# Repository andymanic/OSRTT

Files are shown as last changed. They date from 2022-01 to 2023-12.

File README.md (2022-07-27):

# OSRTT
Open Source Response Time Tool - LCD response time tool, includes hardware, firmware and software!

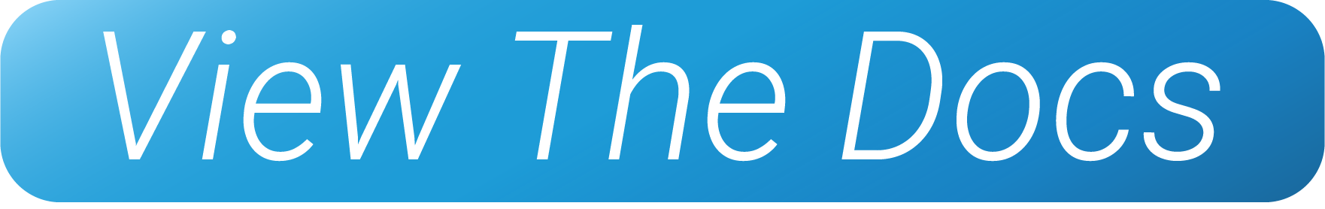
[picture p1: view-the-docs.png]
View the docs

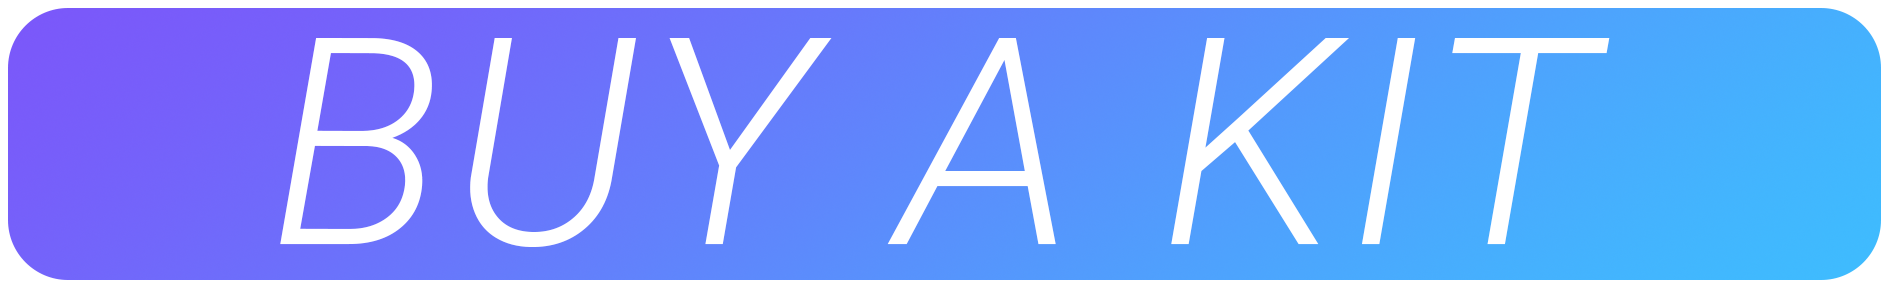
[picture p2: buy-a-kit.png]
Buy a kit


# Project Aim
The goal of this project is to offer an open source, cost effective solution to testing LCD monitor's input lag. The hardware as described in the circuit diagrams is required, as is a copy of the Windows Forms app. The hardware isn't too difficult to build if you'd like to do it yourself, and the software is fully open source so you are welcome to make alterations to suit your testing needs.

The C# based program handles all interaction with the hardware, primarily over Serial (over USB), both connecting to the board, updating the board's firmware (using the [Arduino CLI](https://github.com/arduino/arduino-cli), and recording results. It's also capable of setting how many repeats of the test it will do before averaging them out (max supported 10 repeats). 

My aim was to keep everything as transparent as possible, so when a test is begun it will create a numbered folder within the /Results folder using the monitor, refresh rate and connection you are using. It will save the raw results and processed results to individual files for each run, then will output a "FINAL-DATA-OSRTT.csv" file that averages all the processed data. You can now use the Results View form to both view the data as heatmaps, and the raw data in graph form.

# Installation
- Download the latest zip file from the [releases](https://github.com/andymanic/OSRTT/releases) page. 
- Extract the OSRTT folder anywhere you like, personally I keep it on the desktop.
- Run the "OSRTT Launcher.exe" program. On first run it will ask to install additional files, openning a CMD window to run arduino CLI commands.

# Usage
- Assuming you have the hardware built, connect it via USB then run the launcher. **CONNECT IT DIRECTLY TO YOUR SYSTEM, OR AT LEAST A POWERED HUB**
- On the first launch on a new device, you will be prompted to allow installation of additional files. This is installing the Arduino & Adafruit SAMD cores and Adafruit board library in %APP_DATA%\Arduino15. It may take a minute or two, but is necessary to connect to the board.
- Once the launcher has connected to the device, you can set how many times the test should run, what framerate limit to use, if VSync should be enabled and for how long the device should capture each transition.
- You can then launch the test program with the large button at the top of the section.
- Once the test program is up, press the button on the device. Use numbers 1 - 8 to limit the frame rate: 1 = 1000, 2 = 360, 3 = 240, 4 = 165, 5 = 144, 6 = 120, 7 = 100, 8 = 60
- Assuming the monitor's brightness is in the correct range, the device will run through the test sequence. By default it will run 3 times, although you can set that in the launcher. 

# Building from source
If you'd prefer to compile it yourself, you'll need to download the latest [Arduino CLI](https://github.com/arduino/arduino-cli), and place it in a folder called "arduinoCLI" in the working directory of the launcher. 

# Current hardware limitations
- ~160 nits of brightness is the recommended target using the included 3D printed casing. Different Z heights for the sensor to the display lead to differing maximum supported brightness levels and vary the noise level
- The current design doesn't effectively filter all monitor backlight strobing frequencies. This doesn't affect the final results too heavily but is worth noting here.
- 10 repeats of the test are the maximum the current version of the firmware - this isn't a fixed limit and could be changed in future

# Current software limitations
- The processing algorithm doesn't currently measure cumulative deviation. Luckily I don't think it'd be all that hard to add, and since all the raw data gets saved already you can always re-import any existing folders to re-process that data with any changes to the alogrithm!
- The serial connection isn't perfect - I'm sure this could be made better so if you've done reliable data transfer over serial with C# please do have a look! My biggest issue is with the amount of data, it's likely upwards of 50KB per line so the in buffer size is now 64KB just in case.

# Current human limitations
Please be patient when it comes to solving issues or implementing new feature requests. I'm only human, a bearly functional one at that. I struggle with mental and physical limitations and disabilities, and run both [TechteamGB](https://youtube.com/techteamgb) and [At The Wheel](https://youtube.com/c/atthewheel), and run the short linking platform [Locally Links](https://locallylinks.com), so please excuse any delays. 

# Support the project
If you would like to support this project, there are a number of both direct and indirect ways to help. As stated above, the main goal of this project is to create an accessible solution for testing monitor response times. I want as many reviewers and enthusiasts to have the ability to test this with a degree of accuracy that is currently painstaking to reach. 
- Non-monetary support: please do reach out to your favourite reviewers who don't currently test monitor response times and (politely!) ask them to check out the project. 
- Buy one prebuilt by me: I very much appreciate many won't have the equipment, skills or time to build these units themselves, which is why I'm happy to purchase the parts in bulk, solder everything up, flash the bootloader and firmware, and 3D print the case. I'm still finalising that process, so haven't got a final price as of yet but I'm expecting it to be around $100/£75. Ping me [an email](mailto:inbox@techteamgb.com) if you want one!
- Buy me a ~~Beer~~ - ~~Coffee~~ - Cookie. I like cookies. [Paypal](https://paypal.me/techteamgb) | [Patreon](https://patreon.com/techteamgb)

# Warranties & Guarantees
I should make it clear that this software, circuit diagrams, STL and Gerber files, and any hardware bundles I produce, are provided AS-IS. I can't guarantee I've accounted for every possibility or edge case, or even that what I've written will be infinitely reliable. I have it output every step of processing, so if you want to verify any result you can do so manually. 

# Licensing 
I've gone with the GNU GPL V3 License for the whole project, both hardware and software. That means you are free to use anything here as you like, on the condition that anything you make with this is also open source. If you'd like to use anything here in a closed-source project or if you'd like to manufacture the hardware elements commercially, please send me [an email](mailto:inbox@techteamgb.com).

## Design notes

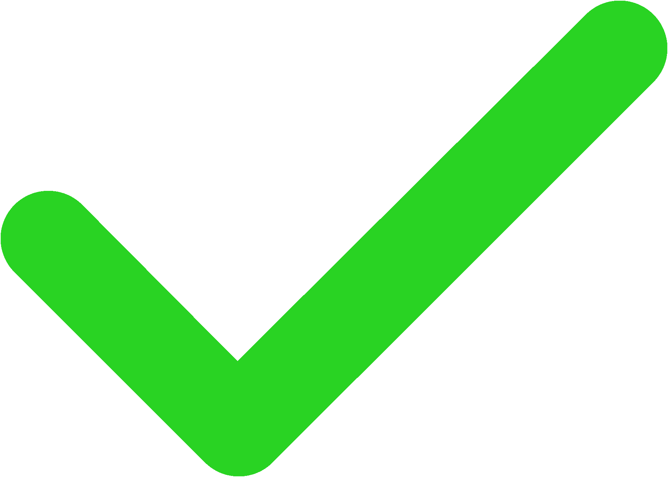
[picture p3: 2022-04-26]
OSRTT Launcher/OSRTT Launcher/Resources/check.png

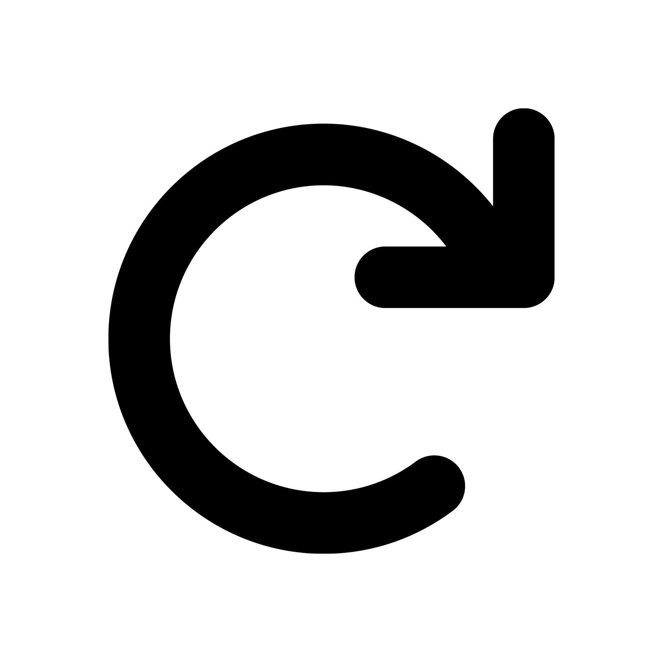
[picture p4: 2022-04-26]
OSRTT Launcher/OSRTT Launcher/Resources/arrow-rotate-right.png

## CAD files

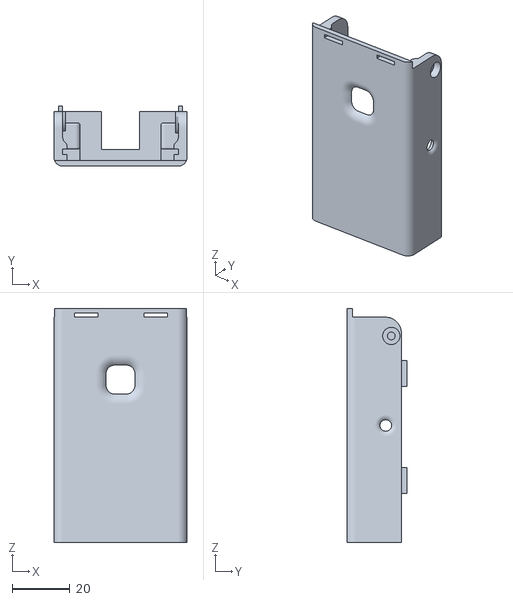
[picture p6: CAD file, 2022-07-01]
Hardware/V4Base.stl
46.0 x 20.9 x 81.0

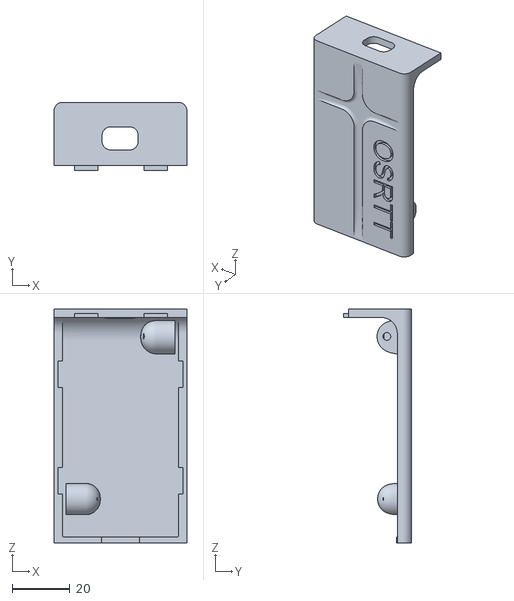
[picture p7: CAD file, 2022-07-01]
Hardware/V4Lid.stl
46.0 x 23.7 x 81.0

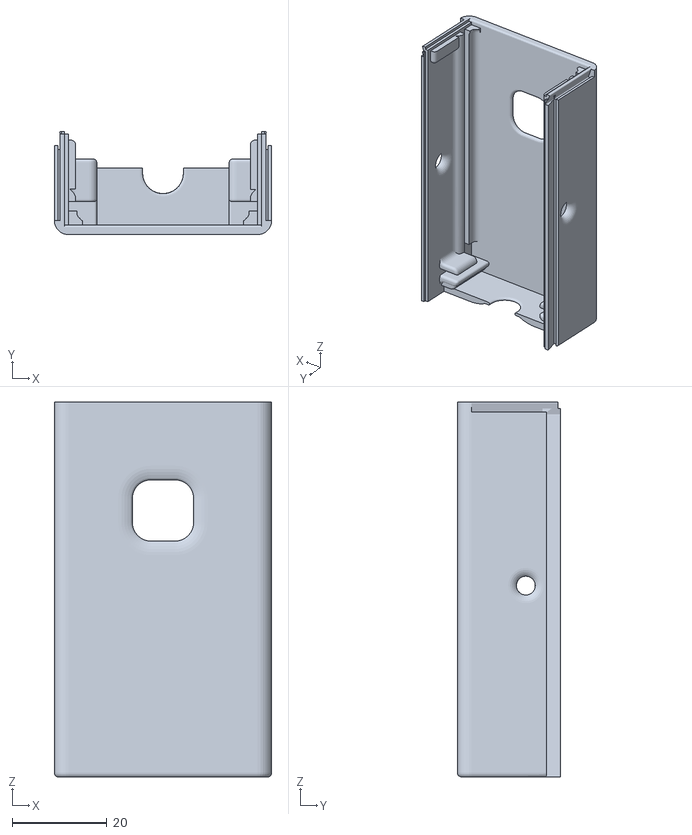
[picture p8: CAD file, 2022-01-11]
Hardware/V3Base.stl
46.0 x 21.9 x 79.4

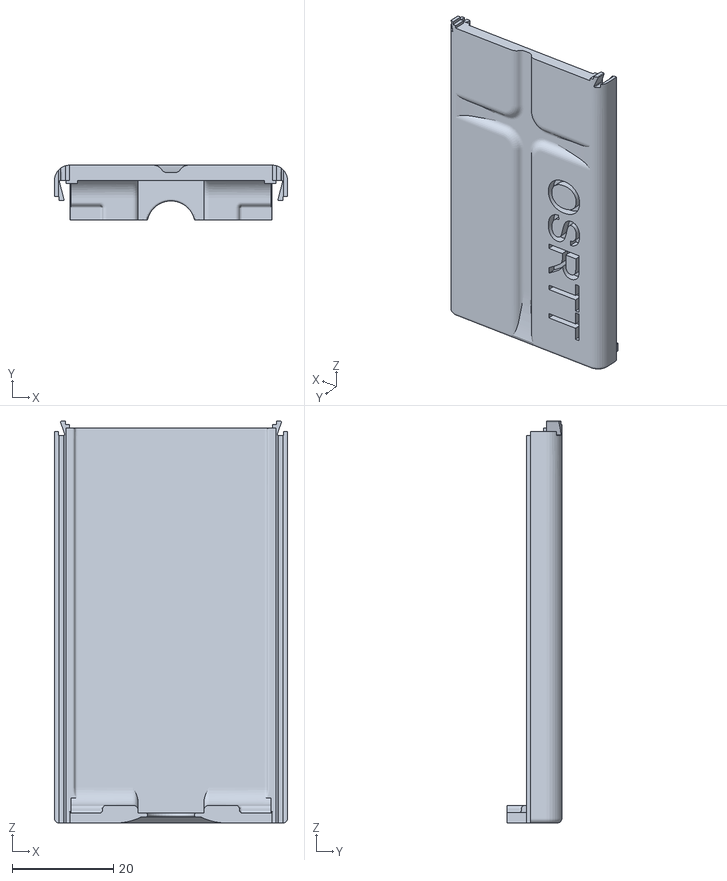
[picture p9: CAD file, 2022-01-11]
Hardware/V3Top.stl
46.0 x 10.8 x 79.4

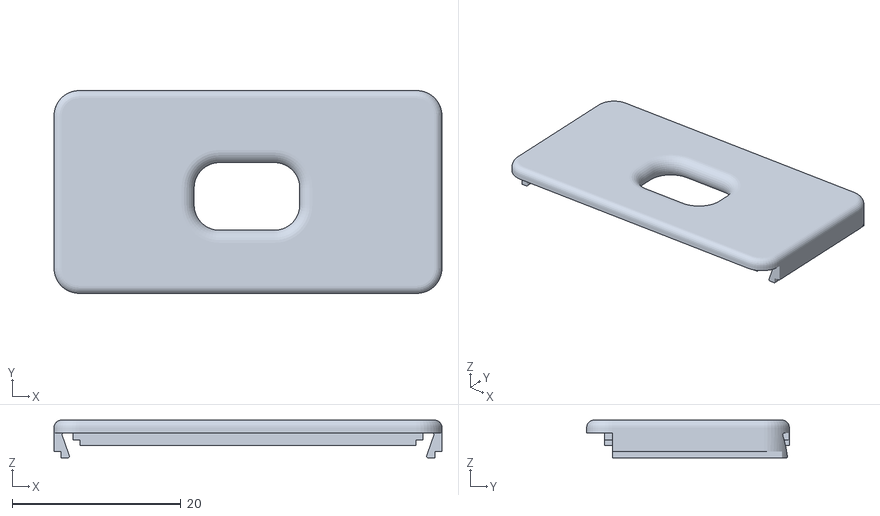
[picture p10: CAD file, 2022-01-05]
Hardware/V3Back.stl
46.0 x 24.0 x 4.50

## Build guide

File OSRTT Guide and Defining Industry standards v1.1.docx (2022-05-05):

OSRTT Guide – Understanding the Many Options, Deciding on Recommended Settings, and Ensuring Consistency Across Reviewers
Issue 1.1, last update 4 May 2022

Introduction

The OSRTT provides a wide range of options and features designed to test all elements of a display’s performance for pixel transitions and response times. There are many ways to analayze the data, and many possible ways you may wish to present the data to your readers and viewers depending on what you are trying to capture and cover. To ensure there is consistency across the industry as much as possible, and clear guidance for an average consumer trying to make sense of the data, it’s important that we try to retain some level of uniformity if we can in the way this data is presented.

This guide is to explain what the different options and measurements methods can do, how they might be interpreted and how ideally they should be presented to readers/viewers to achieve that consistent approach. It covers the “g2g” response time measurements as well as “overshoot” calculations.

The guide has been produced in conjunction with several established reviewers who already carry out this kind of testing, including TFTCentral and Hardware Unboxed. The aim is for it to represent an “industry standard” for this kind of display measurement if possible.

TL;DR: Summary of Recommendations

- Make sure you have consistency in your PC and display setup for this testing wherever possible (explained below)
- When presenting G2G measurements please try and use the suggested names in this guide – please do not bundle everything under the name “response time” without explanation of what you are presenting as there are many different approaches possible
- Please state which method you are using if possible including any tolerance levels etc as it helps ensure results can be compared between reviewers
- The OSRTT ‘recommended settings’ option can be left selected if you wish although it is probably useful to understand what it is capturing and what will be output in the results as explained below. This mode uses:
  - Gamma corrected response times
  - The “complete response time” (this is always captured in the data, no matter what options you select)
  - “Initial response time” (the bit before any overshoot – explained later) with a fixed RGB 5 offset tolerance level
  - “Visual response time” (including any overshoot in the figure – explained later) with a fixed RGB 5 offset tolerance level
  - Gamma corrected overshoot in RGB values
- If you instead want to instead use other settings away from the ‘recommended settings’ mode you can select “advanced settings” in the menu, but please take note of the guide below when selecting options, and when presenting data to your audience.

PC and Display Setup

1. Make sure the display you are measuring has been warmed up for a suitable amount of time, at least 30 minutes. Ideally you would run some dynamic content like a game, video or perhaps leave the full screen version of this TestUFO.com (https://www.testufo.com/photo) test running if you want. The OSRTT software will warn you if it detects you might not have warmed up for long enough
2. Make sure that you have monitor features like blur reduction mode (which would strobe the backlight) or any local dimming disabled. These would cause variations in the light measurement and lead to errors in calculations.
3. Set your graphics card to the refresh rate you want to measure:
  a. For PC gaming usage it is best to set it to the maximum the screen will support. The software will allow you to measure the impact of VRR (Variable Refresh Rates – G-sync and FreeSync) where the frame rate drops below this, by limited the FPS settings, so you do not need to change the refresh rate setting for that.
  b. You may also want to test the screen at a fixed refresh rate for certain situations. For instance, you may want to set the graphics card refresh rate to a fixed 60Hz input, and disable G-sync / FreeSync to simulate the performance if you had a Blu-ray player or 60Hz games console connected. Likewise you could also set the refresh rate at 120Hz to capture the performance for a 120Hz input from modern consoles like the PS5 or Xbox Series X.
4. Position the device so it is measuring the centre of the screen as best you can – the actual sensor is located behind the purple light you can see on the front of the unit, so use that as a guide.
5. If the screen supports VRR (G-sync or FreeSync) then for PC gaming it is probably best to test with this enabled. Some screens show different performance with VRR turned on and off, so it’s probably best to measure with this on since most people will use this feature.

Notes, warnings and comments:

1. Displays that still feature PWM for backlight dimming (thankfully very rare nowadays) may create issues with the measurements since the brightness will fluctuate and this may mess up the calculations. It should be possible to still calculate response times but you may need to more closely validate or calculate the results using the ‘Graph View Template’ sheet. The software uses a moving average filter to reduce noise before processing the data. It’s adaptive based on how noisy the data is, although in some very niche cases it may fail to process, hence the need to check and validate your results.
2. On some displays where the transitions reach towards black, and the contrast ratio of the display is low, you may find the results hard to capture. You may need to exclude these from your results table if the figures look odd. You can also check the data in the ‘Graph View Template’ sheet if you want
3. Why not capture more transitions in the table? – after lots of experimentation and discussion we felt that more data was not necessarily better here. It over-complicated things for readers, added unnecessary time to testing, and created issues with measurements when transitions were very close together. We felt that the provided 30 transitions was the most appropriate sample set to use
4. Please remember these measurements and numbers can never fully replace the need for subjective assessment in games, movies and other fast motion content.

What do we mean by display pixel “response time”? – it might not be as simple as you think

First of all, we should consider what the term “response time” really means in the display market. It is not as simple as just saying “it’s the time it takes for a pixel to change from one colour to another”. That’s not actually what the term “response time” means strictly.

For over 20 years the definition of response time in the display market is actually, in simple terms: “the time taken to switch between two colours, allowing for a small leeway of 10% either side”. Put another way, “It’s the time to go from close to the starting colour, to close to the end colour”.

Actually we are measuring changes in grey shade of the pixels based on how much light they let through from the backlight (for LCD displays at least), from RGB 0 (black) to 255 (white). The colour filters are applied on top so from now on we will talk about this as changes in grey shade, which is where the term “grey to grey” (G2G / GtG) comes from in the market.

Represented on a graph measuring the change, it would look something like this:

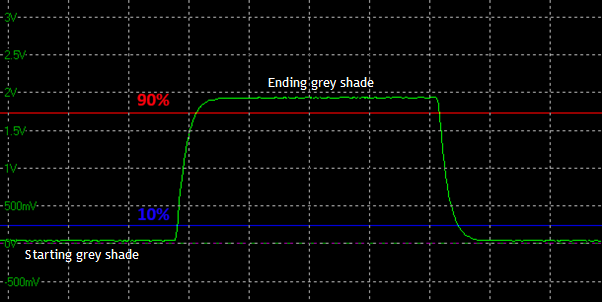
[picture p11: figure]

Where the bottom green line of the graph is the darker grey shade it is changing FROM, and the top green line represents the lighter grey shade it is changing TO. The light from the display is picked up by a photosensor or similar device and converted to a voltage on the graph.

The time it takes to switch from the bottom green line (dark shade) to the top green line (light shade) would be the full transition time of the change, but actually the definition of the “response time”, as defined a long time ago and uniformly adopted by panel and display manufacturers, is the time it takes to change within a 10% tolerance of either shade. That’s represented by the 10% blue line close to the starting grey shade, and to the 90% red line which is close to the end grey shade. That’s what the term “response time” officially means in the display industry.

The reasons for this being adopted were:

1) Because having a modest 10% tolerance level is widely adopted in various areas of electronics and measurement, so it seems to make sense to do the same here
2) It helps to some degree reflect a more realistic view of the time it takes to get “close enough” to the desired colour from a visual point of view. For instance, if you’re transitioning to black, there is a point where very dark grey is “close enough” to look visually indistinguishable and very similar. A small tolerance accounts for this leeway in what you see visually. This is a good thing for displays as after all, it’s all about what you see as a user.
3) It also helps avoid some complications with measurement methods, removing any noise or variation as you get close to certain shades, especially towards black.

Let’s call this the “traditional response time” for reference.

If you want to, you can measure using this method from OSRTT by

- Select the test settings menu > switch to advanced mode at the top > in response time settings section select tolerance style as “light level” > select “10% light level” option as shown below.

We do not believe that this is the best way to present this measurement data any more, and would advise using the other methods discussed below. It is included for completeness and reference.

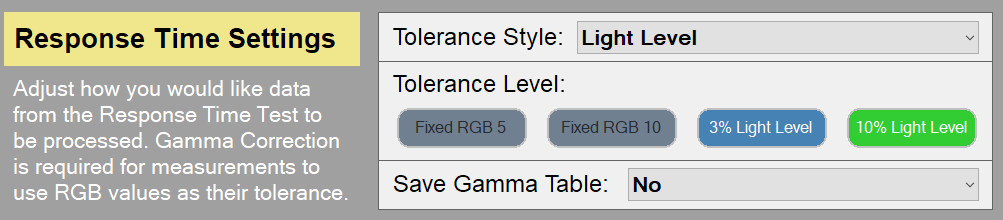
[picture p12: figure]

Gamma Correction provides a more accurate view of visual experience

So that’s the definition of what “response time” actually means officially. In 2020 a video by a5hun at Aperturegrille on YouTube (https://www.youtube.com/watch?v=MbZUgKpzTA0), and then later discussed at length by Hardware Unboxed (https://www.youtube.com/watch?v=-Zmxl-Btpgk) and TFTCentral (https://tftcentral.co.uk/articles/response_time_testing) highlighted a flaw with the traditional measurement method. This old method did not account for the impact of display gamma, and so the way the tolerance levels of 10% and 90% were used led to some issues.

You can refer back to the resource linked above for a lot more information, but a better method was suggested that would “gamma correct” the measurements and therefore provide a more realistic reflection of the performance from a visual point of view. The tolerance levels of 10 and 90% can still be kept if desired, but now the measurements are based on the actual visual RGB values instead of just the voltage that is converted from the light output. This removes the error with just referring to voltage scales on the data that were being used before in the “traditional response time method”.

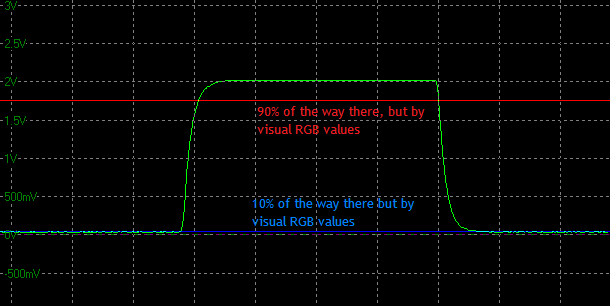
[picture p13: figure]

This is useful to provide a more complete view of what you would see in real use and we would recommend leaving “gamma corrected response times” enabled in the software, unless you have some specific reason to measure using the old traditional method.

- Select the test settings menu > switch to advanced mode at the top > in response time settings section select tolerance style as “RGB values (Gamma corrected)l” > select “10% light level” option as shown below.

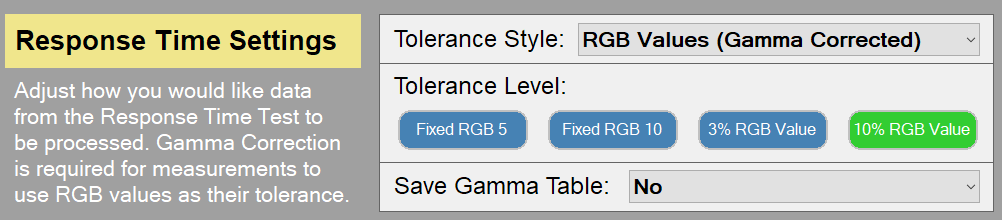
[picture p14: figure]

From there the question becomes – what is a reasonable tolerance / offset level to use, if any, and which part of the response curve do you want to capture?

-----------------------------------------------------------------------------------
Option 1 – Measure the Complete Response Curve (0 – 100%)
Known as the “Complete Response Time”

One option for the OSRTT tool is to consider the FULL transition time, the time it takes to fully change from one shade to another. This would be represented on the response curve graph as follows, measuring between the blue and the red lines without any tolerance baked in. It is the total time taken to fully change from the starting grey shade, to the target grey shade.

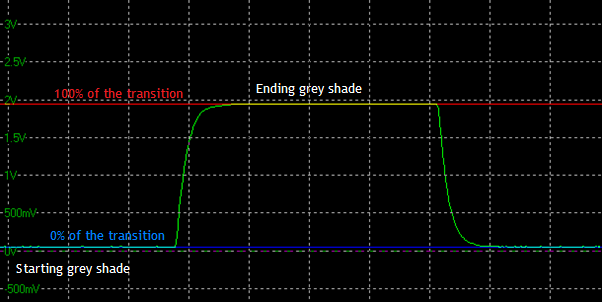
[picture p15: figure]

This may be favoured by some people as a measure of the full transition time – but we cannot call this the “response time” really as that’s not what we are measuring any more.

The recommendation is that if this data is to be used and presented, this should really be labelled as the COMPLETE RESPONSE TIME

Some people may prefer this approach as a very strict measure of the total time it takes to switch from one shade fully to another. However, there are some limitations with this approach:

1) There is no consideration for when a transition has reached “close enough” to the target colour and so is visually indistinguishable. Is it fair to measure the curve to where it has to reach the final end shade if it got visually to the same thing much sooner? You will see how the response curves taper off when it gets close to the end points of the transition. The real question is how close does it need to get to visually represent the completion of the transition?
2) Some screens show a particularly long taper at the end of a transition as it finishes that last little bit. In some extreme cases if you were then measuring this “total transition time” it would extend the response time to maybe 20ms+. Is it fair to do that when it ctually reached 90% or even 95% of the way there, and looked visually the same?
3) Note: Where overshoot is present (discussed later) the “complete transition time” will incorporate this as well, as it measures the time it takes to get to the final RGB state AFTER the overshoot has happened. This will also add significant time to the G2G measurement. This is discussed more later, but it’s important to keep in mind for these measurements.

There is perhaps merit and interest in capturing this “complete response time” for some users, but we also need to also keep in mind what we are ultimately trying to achieve here – and that is to provide a measurement that is representative of how the display appears visually to the user. As a result we do not recommend using the ‘total response time’ as it is overly strict and prone to causing unfair measurements.

Note that if you do want to use this data, is is captured by default in the OSRTT output data CSV files as “complete response time”, you do not need to select that in the software, it will always be included

-----------------------------------------------------------------------------------------------------------
Option 2 – Using a tight tolerance level to capture nearly all the initial response time curve (3 – 97%) but excluding overshoot

At the time of writing in Mar 2022 this is the method currently used by Hardware Unboxed and discussed in their video here (https://www.youtube.com/watch?v=-Zmxl-Btpgk&feature=youtu.be). The desire is to capture as much of the response curve as possible, but eliminating some of the problems discussed above with getting very close to the desired shade, removing the issue with the slow tapering off, and also ignoring the overshoot impact in the response time figure itself. Overshoot is captured as a separate table of data, it is not just ignored.

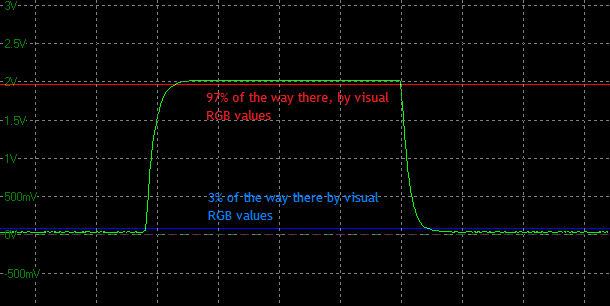
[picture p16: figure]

This can be selected within OSRTT using the following option:

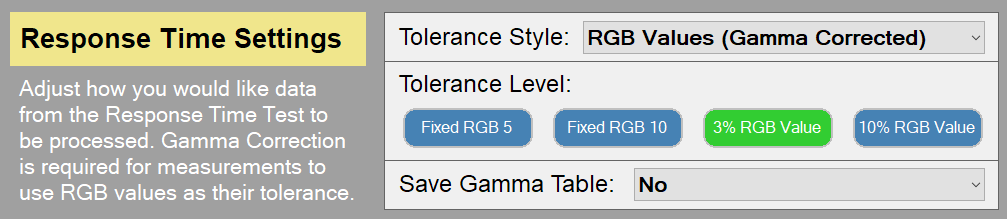
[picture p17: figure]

This avoids some of the issues in presenting the “complete response time” but also has some limitations of its own:

1) The % will result in the actual RGB tolerance being variable each time. For instance when measuring from 0 > 100 RGB as a transition, this would mean you’re really measuring between RGB 3 and RGB 97 values. But if you measure from 0 > 200 RGB you are measuring between RGB 6 and RGB 194 because the total range is wider. So on the one hand, it is being more strict and only allowing an RGB tolerance of 3, and in the other it’s measuring a slightly more relaxed tolerance of 6.  This doesn’t make a huge difference to the resulting measurements as really it’s trying to capture nearly the whole “total transition time” anyway, but it does cause some variance.
2) Like with the “total transition time” approach, it doesn’t necessarily consider the visual difference as well and whether a shade gets “close enough” sooner than the strict tolerance levels used, especially when measuring transitions close together. It may also in some cases capture portions of the slow tapering off in the grey shade, where it may be visually indistinguishable in practice.

We do not recommend using a % tolerance level for the above reasons

----------------------------------------------------------------------------------------------------------
Option 3 – Using the original tolerance levels but now with gamma correction
(10 - 90%)

There is of course the option to stick with the original 10 – 90% tolerance levels that have been used in the market for 20+ years. It is worth including the gamma correction to more accurately capture the response times relative to what you see in RGB values. This removes some of the errors in sticking only to the voltage reading on the graphs, and allows you to account for display gamma.

The options should be selected as follows in the OSRTT software:

The limitations with this approach are:

1) Like with the 3 – 97% tolerance levels discussed above, using any % will result in the actual RGB tolerance being variable each time. In this instance when measuring from 0 > 100 RGB, this would mean you’re really measuring between RGB 10 and RGB 90. But if you measure from 0 > 200 RGB you are measuring between RGB 20 and RGB 180 because the total range is wider. So on the one hand, it is being more strict and only allowing an RGB tolerance of 10, and in the other it’s measuring a more relaxed tolerance of 20.  Visually you are not being consistent in the tolerance allowed to get “close enough” to the end shade. This is far more variable when using 10/90% tolerance levels. If you are going to the lengths of correcting for gamma in the response times in order to provide a better indication of visual experience, this variation may not be ideal.

We do not recommend using a % tolerance level for the above reason

-------------------------------------------------------------------------------------------------------
Option 4 – Fixing an RGB tolerance level with gamma correction (+/- RGB 10)

This the approach favoured by TFTCentral in their measurements. Gamma correction is used to provide a more realistic measurement of what you see visually, accounting for display gamma and avoiding the pitfalls and errors from the old “traditional response time” method.

To overcome the issues with using a % discussed in the above options 2 and 3, and having variable RGB tolerance depending on the size of the range as a result, a fixed RGB tolerance level is selected. Based on lengthily visual experimentation and testing, an RGB balance of +/- 10 was deemed appropriate to get “close enough” to the desired grey shade from a visual point of view without being overly strict or too relaxed.

The TFTCentral article (https://tftcentral.co.uk/articles/response_time_testing) explains the approach and how they reached this method in more detail. This can be selected in OSRTT using the following option:

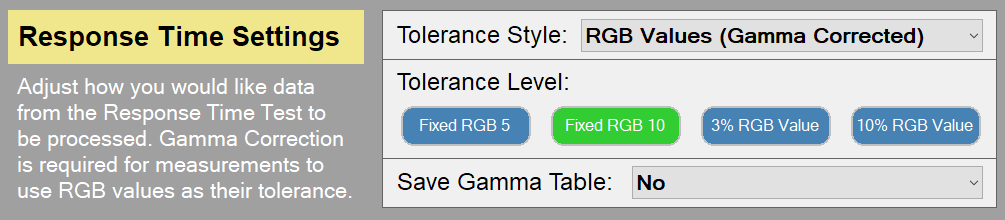
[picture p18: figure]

One possible concern with this approach is that for transitions that are close together (e.g. 0 – 51), there would not be much of the transition curve to measure, as you would be measuring from RGB 10 to RGB 41 in theory. This could still be considered “fair” visually since the two shades you are switching between are already very close together. Obviously if you were measuring something even closer like 0 > 20 RGB, you’d be measuring a range of 0!

You could also instead use…

Option 5 – Fixing a tighter RGB tolerance level with gamma correction (+/- RGB 5)

Instead of using a tolerance of RGB 10, you could use a tighter RGB 5 tolerance. This captures more of the response time curve. This is the default option in the “recommended settings” although you may consider this overly strict from a visual point of view, you would have to decide whether you feel it is a better option than using RGB 10 as being “close enough” to the target grey shade..

If you want to use a fixed RGB 5 tolerance you can select it in the software using the following options:

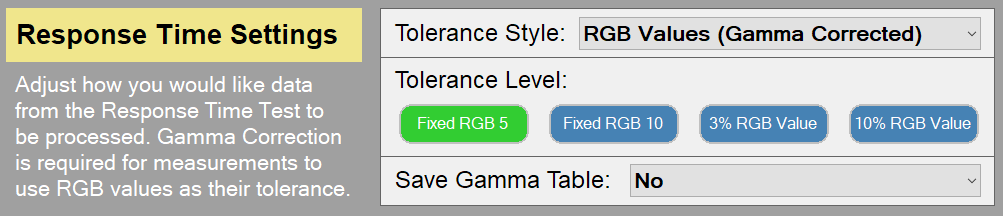
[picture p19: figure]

We recommend using a fixed RGB tolerance level when measuring G2G response times, you can use either RGB 10 or RGB 5 depending on your preference. TFTCentral have settled with RGB 10 as explained in their article here (https://tftcentral.co.uk/articles/response_time_testing).

Overshoot Calculations

Above covers the pixel transition times and “G2G” figures. The other aspect that can be measured by OSRTT is “overshoot”. On a response time measurement graph the overshoot would be represented by the peak where the shade reaches beyond the desired grey shade, before it then drops back down to where it was supposed to be. This can also appear on the downward “fall time” as well at the end of the curve which would be “undershoot”.

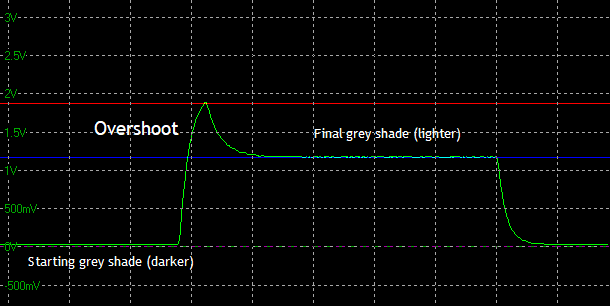
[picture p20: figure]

There are a few options included within the software for this:

1) Gamma corrected (RGB values) overshoot – RECOMMENDED - this will measure how many RGB values the pixel transition overshoots the desired shade. This is the recommended approach. Select RGB values (Gamma Corrected) > Raw RGB values in the settings as shown below.
2) RGB value Percentage – while not within the official “traditional response time” method defined in the industry 20+ years ago, the long standing approach has been to use a % to define how much the shade overshoots its target. This has always been based on light level readings, without gamma correction. Hopefully you can see why switching to RGB values and gamma correction is useful for these measurements.  If you really wanted you could do this as a % overshoot in RGB values as well, although it is not recommended. This can be selected as well within the software for completeness, but again has issues with variation. For instance if you measure 0 > 50 RGB and the shade overshoots by a fairly modest and hard to distinguish 10 RGB values, that would be a 20% overshoot and would be considered “high”. That difference of only 10 RGB values is not very visible in practice. If the transition being measured was 0 > 200 RGB instead and it overshoots by the same 10 RGB values, that would now only be 5% overshoot, even though it’s the exact same RGB difference. This is why the % method is flawed and creates issues with overshoot presentation.

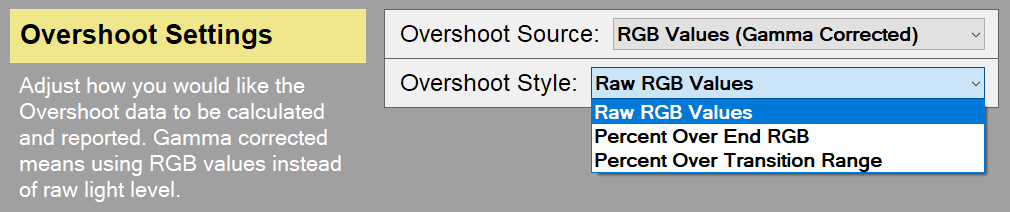
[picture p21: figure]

The light level % can also be selected within the overshoot section if you really want to:

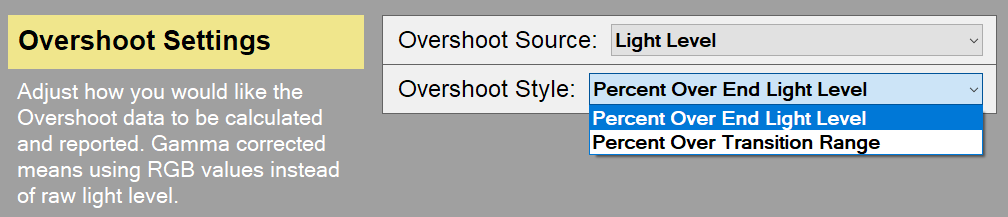
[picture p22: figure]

If you are experimenting with using % for overshoot there are two options available. This wil calculate the % depending on whether 1) you’re only considering how far beyond the end voltage value it goes. i.e only the target final voltage is considered along with the overshoot voltage, or 2) You’re considering the overshoot as a portion of the overall curve (end-start) setting. i.e. the range of the transition is considered in the calculation. Again these methods are not recommended for accurate overshoot calculations.

The recommendation for a fairer reflection of overshoot is using the gamma corrected “RGB value overshoot” option.

A note about Measuring the G2G response times which includes overshoot

One note that we mentioned earlier about the “Complete Response Time” (0 – 100%) is that it will incorporate the overshoot time as well. It measures the full time it takes to go from the starting grey shade, to the final grey shade AFTER any overshoot has taken place. It’s the time it takes to reach and settle on the grey shade it was trying to reach, not when it first reaches that shade before the overshoot appears. This basically captures the length of the overshoot in the response time figure as well.

For the “Complete Response Time” on the graph it would be measuring the time between the two yellow lines for example:

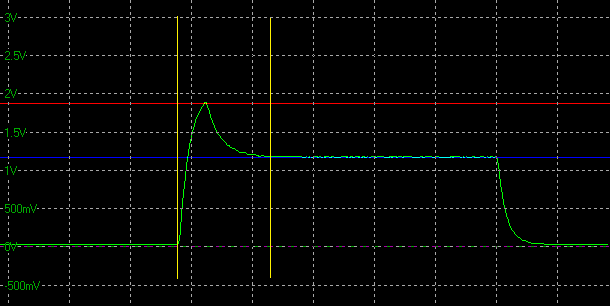
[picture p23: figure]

---------------------------------------------------------------------
Initial Response Time vs. Perceived Response Time

In the calculation you will see two response times presented in your data – regardless of which other settings you have choosen. These are the “initial response time” and the “perceived response time”. These will both consider any overshoot differently.

Initial Response Time

This is the method that has been used in the market for a long time. The response time is measured on the part of the curve BEFORE the overshoot peak. It captures how long it takes to reach the desired shade, or to the desired tolerance level, but ignores the fact that the screen then overshoots this shade and then takes a while to reach back down. It would be capturing the time between the two yellow lines on the below graph:

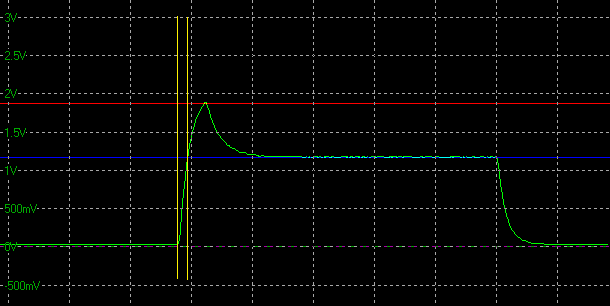
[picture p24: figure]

The problem with this is that it does not then capture in that response time figure the fact that there is an overshoot, and in reality it will take quite a bit longer to reach back to the desired end grey shade. Is it fair to reward a screen with a very low response time G2G figure when the overshoot might take a long time to disappear?

In this “initial response time” approach the overshoot is not forgotten, it is represented in a separate table showing the severity of the overshoot peak, preferably using gamma corrected RGB overshoot as discussed above.

It is still fine to present the “initial response time” in this way, but if overshoot is present this must be considered and presented alongside the G2G response times. This is the approach that has been used in the market for 20+ years so is the most widely recognised, and easiest to provide comparisons with over all the years’ worth of testing.

Pereceived Response Time

This is an alternative approach and is presented in the output data of any measurement. If overshoot is present it is captured in the G2G response time figure as well, representing the time it takes to settle back down to the final shade (or close to it when using a tolerance level) AFTER any overshoot has disappeared. It is the “perceived response time” as it considers the impact of the overshoot in the G2G figures. This may be a useful method to use if you wanted to show fewer data sets in your results, or were not including a normal overshoot table for instance.

On the graph it would look like this:

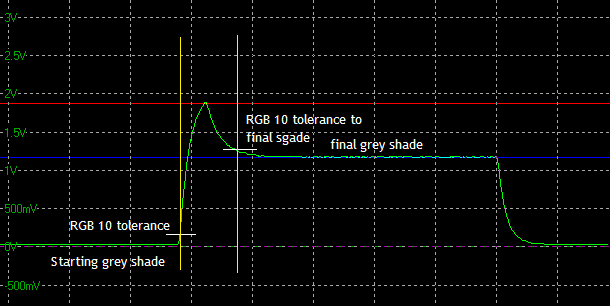
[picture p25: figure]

So keep in mind that if you are presenting the “complete response time” or the “perceived response time” data, and there is overshoot present, that will be captured in the G2G figure, and may explain why some are longer times.

If you use the “initial response time” figures, the G2G response time will be measured to where the shade is first reached, ignoring the fact there is then a large overshoot before it settles back to where it should be. An overshoot table should definitely be included along side the response time data if this method is used.

Visual Response Rating
Please note this is a work in progress and subject to change and improvements

Especially when presenting just the “perceived response time” (which incorporates the overshoot as well as explained above), you lose a potentially important piece of information which is how quickly the display can move away from the initial colour - regardless of any overshoot. This is important as while the total transition time is incredibly key, from a visual perspective, you are likely to have a better viewing experience on a panel that is fast to reach it’s target colour, even if it misses it slightly, than a display that takes the same complete transition time but is just much slower to get there.

The “Visual Response Rating” has also been added as a potentially useful additional metric. It is a finite score rather than a direct measurement. The calculation is pretty simple, it’s: “100 – (Initial Response Time + Perceived Response Time)”. Since both metrics are using the same tolerance level, if a display doesn’t overshoot both times will be identical. This essentially rewards displays that are fast with a small amount of overshoot over displays that aren’t as fast even if they don’t overshoot at all – while still overall preferring ultra-fast, accurate monitors.

Some examples may help explain – these are theoretical rather than direct measurements:

Initial Response Time | Perceived Response Time | Visual Response Rating
2.8ms | 2.8ms | 94.4
2.8ms | 5.6ms | 91.6
5.6ms | 5.6ms | 88.8
3.8ms | 9.1ms | 87.1
10.8ms | 10.8ms | 78.4

Total System Latency Testing

OSRTT also includes a handy measurement of the total system latency, in a similar way to tools like NVIDIA LDAT or NVIDIA Reflex Latency. More information about both tools is available on TFTCentral here (https://tftcentral.co.uk/articles/nvidia_reflex).

It’s important to note that this is NOT capturing the monitor input lag on its own, which would be the lag of the display causing by the signal processing. That will be incorporated within the overall latency number somewhere, but this is basically capturing “click to photon” end to end latency. This can be influenced by many factors including graphics card, mouse, system settings, refresh rate, monitor etc. It’s a useful tool for measuring and comparing and optimising your end to end overall total system latency, but should NOT be used to represent the lag of the monitor (often referred to as “input lag”) as this cannot be isolated from within the measurement, and there are too many variables at play.

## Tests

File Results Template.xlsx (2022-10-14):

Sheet: PASTE DATA HERE
Starting RGB | End RGB | Complete Response Time (ms) | Initial Response Time - RGB5 (ms) | Perceived Response Time - RGB5 (ms) | Overshoot (RGB) | Visual Response Rating | Input Lag (ms)
0 | 51 | 1 | 1 | 1 | 1 | 1 | 1
51 | 0 | 1 | 1 | 1 | 1 | 1 | 1
0 | 102 | 1 | 1 | 1 | 1 | 1 | 1
102 | 0 | 1 | 1 | 1 | 1 | 1 | 1
0 | 153 | 1 | 1 | 1 | 1 | 1 | 1
153 | 0 | 1 | 1 | 1 | 1 | 1 | 1
0 | 204 | 1 | 1 | 1 | 1 | 1 | 1
204 | 0 | 1 | 1 | 1 | 1 | 1 | 1
0 | 255 | 1 | 1 | 1 | 1 | 1 | 1
255 | 0 | 1 | 1 | 1 | 1 | 1 | 1
51 | 102 | 1 | 1 | 1 | 1 | 1 | 1
102 | 51 | 1 | 1 | 1 | 1 | 1 | 1
51 | 153 | 1 | 1 | 1 | 1 | 1 | 1
153 | 51 | 1 | 1 | 1 | 1 | 1 | 1
51 | 204 | 1 | 1 | 1 | 1 | 1 | 1
204 | 51 | 1 | 1 | 1 | 1 | 1 | 1
51 | 255 | 1 | 1 | 1 | 1 | 1 | 1
255 | 51 | 1 | 1 | 1 | 1 | 1 | 1
102 | 153 | 1 | 1 | 1 | 1 | 1 | 1
153 | 102 | 1 | 1 | 1 | 1 | 1 | 1
102 | 204 | 1 | 1 | 1 | 1 | 1 | 1
204 | 102 | 1 | 1 | 1 | 1 | 1 | 1
102 | 255 | 1 | 1 | 1 | 1 | 1 | 1
255 | 102 | 1 | 1 | 1 | 1 | 1 | 1
153 | 204 | 1 | 1 | 1 | 1 | 1 | 1
204 | 153 | 1 | 1 | 1 | 1 | 1 | 1
153 | 255 | 1 | 1 | 1 | 1 | 1 | 1
255 | 153 | 1 | 1 | 1 | 1 | 1 | 1
204 | 255 | 1 | 1 | 1 | 1 | 1 | 1
255 | 204 | 1 | 1 | 1 | 1 | 1 | 1
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

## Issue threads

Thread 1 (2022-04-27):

Unhandled Exception, could not load scottplot.winforms 4.1.41.0

Axaion, 2022-04-27:
When clicking "Heatmap & Graphs" on the menu bar at the top, nothing happens, if i click it in the application window, im getting this error.
I think the version might be mismatched? the scottplot in the 2.4 release has scottplot.dll version 4.1.32.0, but its looking for 4.1.41.0
Just a guess though

Heres the error log

See the end of this message for details on invoking
just-in-time (JIT) debugging instead of this dialog box.

************** Exception Text **************
System.IO.FileNotFoundException: Could not load file or assembly 'ScottPlot.WinForms, Version=4.1.41.0, Culture=neutral, PublicKeyToken=5df1dfa5321e734b' or one of its dependencies. The system cannot find the file specified.
File name: 'ScottPlot.WinForms, Version=4.1.41.0, Culture=neutral, PublicKeyToken=5df1dfa5321e734b'
   at OSRTT_Launcher.ResultsView.InitializeComponent()
   at OSRTT_Launcher.ResultsView..ctor()
   at OSRTT_Launcher.Main.resultsViewBtn_Click(Object sender, EventArgs e)
   at System.Windows.Forms.Control.OnClick(EventArgs e)
   at System.Windows.Forms.Button.OnClick(EventArgs e)
   at System.Windows.Forms.Button.OnMouseUp(MouseEventArgs mevent)
   at System.Windows.Forms.Control.WmMouseUp(Message& m, MouseButtons button, Int32 clicks)
   at System.Windows.Forms.Control.WndProc(Message& m)
   at System.Windows.Forms.ButtonBase.WndProc(Message& m)
   at System.Windows.Forms.Button.WndProc(Message& m)
   at System.Windows.Forms.NativeWindow.Callback(IntPtr hWnd, Int32 msg, IntPtr wparam, IntPtr lparam)

WRN: Assembly binding logging is turned OFF.
To enable assembly bind failure logging, set the registry value [HKLM\Software\Microsoft\Fusion!EnableLog] (DWORD) to 1.
Note: There is some performance penalty associated with assembly bind failure logging.
To turn this feature off, remove the registry value [HKLM\Software\Microsoft\Fusion!EnableLog].

************** Loaded Assemblies **************
mscorlib
    Assembly Version: 4.0.0.0
    Win32 Version: 4.8.3928.0 built by: NET48REL1
    CodeBase: file:///C:/Windows/Microsoft.NET/Framework64/v4.0.30319/mscorlib.dll
----------------------------------------
OSRTT Launcher
    Assembly Version: 2.0.0.3
    Win32 Version: 2.0.0.3
    CodeBase: file:///C:/OSRTT%20Launcher/OSRTT%20Launcher.exe
----------------------------------------
System.Windows.Forms
    Assembly Version: 4.0.0.0
    Win32 Version: 4.8.3928.0 built by: NET48REL1
    CodeBase: file:///C:/WINDOWS/Microsoft.Net/assembly/GAC_MSIL/System.Windows.Forms/v4.0_4.0.0.0__b77a5c561934e089/System.Windows.Forms.dll
----------------------------------------
System
    Assembly Version: 4.0.0.0
    Win32 Version: 4.8.3928.0 built by: NET48REL1
    CodeBase: file:///C:/WINDOWS/Microsoft.Net/assembly/GAC_MSIL/System/v4.0_4.0.0.0__b77a5c561934e089/System.dll
----------------------------------------
System.Drawing
    Assembly Version: 4.0.0.0
    Win32 Version: 4.8.3761.0 built by: NET48REL1
    CodeBase: file:///C:/WINDOWS/Microsoft.Net/assembly/GAC_MSIL/System.Drawing/v4.0_4.0.0.0__b03f5f7f11d50a3a/System.Drawing.dll
----------------------------------------
System.Configuration
    Assembly Version: 4.0.0.0
    Win32 Version: 4.8.3761.0 built by: NET48REL1
    CodeBase: file:///C:/WINDOWS/Microsoft.Net/assembly/GAC_MSIL/System.Configuration/v4.0_4.0.0.0__b03f5f7f11d50a3a/System.Configuration.dll
----------------------------------------
System.Core
    Assembly Version: 4.0.0.0
    Win32 Version: 4.8.3928.0 built by: NET48REL1
    CodeBase: file:///C:/WINDOWS/Microsoft.Net/assembly/GAC_MSIL/System.Core/v4.0_4.0.0.0__b77a5c561934e089/System.Core.dll
----------------------------------------
System.Xml
    Assembly Version: 4.0.0.0
    Win32 Version: 4.8.3761.0 built by: NET48REL1
    CodeBase: file:///C:/WINDOWS/Microsoft.Net/assembly/GAC_MSIL/System.Xml/v4.0_4.0.0.0__b77a5c561934e089/System.Xml.dll
----------------------------------------
AutoUpdater.NET
    Assembly Version: 1.7.0.0
    Win32 Version: 1.7.0.0
    CodeBase: file:///C:/OSRTT%20Launcher/AutoUpdater.NET.DLL
----------------------------------------
WindowsDisplayAPI
    Assembly Version: 1.3.0.13
    Win32 Version: 1.3.0.13
    CodeBase: file:///C:/OSRTT%20Launcher/WindowsDisplayAPI.DLL
----------------------------------------
Newtonsoft.Json
    Assembly Version: 13.0.0.0
    Win32 Version: 13.0.1.25517
    CodeBase: file:///C:/OSRTT%20Launcher/Newtonsoft.Json.DLL
----------------------------------------
Microsoft.CSharp
    Assembly Version: 4.0.0.0
    Win32 Version: 4.8.3761.0
    CodeBase: file:///C:/WINDOWS/Microsoft.Net/assembly/GAC_MSIL/Microsoft.CSharp/v4.0_4.0.0.0__b03f5f7f11d50a3a/Microsoft.CSharp.dll
----------------------------------------
System.Runtime.Serialization
    Assembly Version: 4.0.0.0
    Win32 Version: 4.8.3928.0 built by: NET48REL1
    CodeBase: file:///C:/WINDOWS/Microsoft.Net/assembly/GAC_MSIL/System.Runtime.Serialization/v4.0_4.0.0.0__b77a5c561934e089/System.Runtime.Serialization.dll
----------------------------------------
System.Numerics
    Assembly Version: 4.0.0.0
    Win32 Version: 4.8.3761.0 built by: NET48REL1
    CodeBase: file:///C:/WINDOWS/Microsoft.Net/assembly/GAC_MSIL/System.Numerics/v4.0_4.0.0.0__b77a5c561934e089/System.Numerics.dll
----------------------------------------
System.Dynamic
    Assembly Version: 4.0.0.0
    Win32 Version: 4.8.3761.0
    CodeBase: file:///C:/WINDOWS/Microsoft.Net/assembly/GAC_MSIL/System.Dynamic/v4.0_4.0.0.0__b03f5f7f11d50a3a/System.Dynamic.dll
----------------------------------------
Anonymously Hosted DynamicMethods Assembly
    Assembly Version: 0.0.0.0
    Win32 Version: 4.8.3928.0 built by: NET48REL1
    CodeBase: file:///C:/WINDOWS/Microsoft.Net/assembly/GAC_64/mscorlib/v4.0_4.0.0.0__b77a5c561934e089/mscorlib.dll
----------------------------------------

************** JIT Debugging **************
To enable just-in-time (JIT) debugging, the .config file for this
application or computer (machine.config) must have the
jitDebugging value set in the system.windows.forms section.
The application must also be compiled with debugging
enabled.

For example:

<configuration>
    <system.windows.forms jitDebugging="true" />
</configuration>

When JIT debugging is enabled, any unhandled exception
will be sent to the JIT debugger registered on the computer
rather than be handled by this dialog box.

andymanic, 2022-04-27:
My mistake - version number mismatch. Will push an update to fix that now.

andymanic, 2022-04-27:
Update live: [https://github.com/andymanic/OSRTT/releases/tag/2.5](https://github.com/andymanic/OSRTT/releases/tag/2.5)

Closed 2022-04-27.

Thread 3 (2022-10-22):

Input Lag

alex-i-1, 2022-10-22:
Input Lag - what is it?
There is no info about that on https://andymanic.github.io/OSRTTDocs/
For my understanding, it could begin from:
1) data sending through the cable has began,
2) data sending through the cable has ended.
And it could end at:
1) visual change at 10%,
2) visual change at 80%,
3) visual change at 90%.
Or whenever it begins and ends.
Googling "Click to Photon Latency" didn't help on that either. Single photon? Bunch of photons? That's not a good self-descriptive name.
Is it a subtraction of matrix response time from on-display latency? What is it?
The On-display Lag is actually a vague thing too.
And thanks for starting an open source project.

andymanic, 2022-10-22:
While I will update the docs soon, the topic of "input lag", "input latency", "click to photon latency", "total system latency" or "end to end latency" is nowhere near a new term in the world of monitor testing. It's something most if not all technical reviews cover, and is a pretty standard - and I thought - obvious metric. You are measuring how long an input takes to be displayed. There is variance in how you measure that, whether you measure the end-to-end (click to photon, total system) latency, ie the time between sending an input and it being shown on screen, or the on display latency, ie how long it takes for the monitor to take in a new frame, run any post processing (including overdrive), then display it.

You mentioned you googled "click to photon latency" - but said you didn't find anything useful. I searched it and found my own video ([linked here](https://www.youtube.com/watch?v=RuizPSspt98)), Linus' video ([linked here](https://www.youtube.com/watch?v=aL5YTWRpzoA)), and even a full article on a remote desktop software's website explaining, with graphs, what the metric covers ([linked here](https://www.ni-sp.com/support/click-to-photon-measuring-local-and-remote-display-latencies)).

If you are after specifics on my tool, I have the board measure the USB polling delay, then measure the time between the input being registered with the USB controller, and the display starting to transition from black (RGB 0) to white (RGB 255). I also have the desktop software running some custom DirectX 11 code record the frame time when an event is registered, which can later be subtracted, along with the USB polling time, to give the on display latency. Each of these steps is recorded and displayed though, should you want to quote one specific metric, or get an idea of the bigger picture.

Hope that clears things up.

alex-i-1, 2022-10-23:
That "www.ni-sp.com" site is what I read for first, - it is the one which doesn't describe what "click to photon" means. Simply because it doesn't say what is being counted as the end of the measurement. It describes that moment with the word "detected", but even graphs there are showing that this could mean any point during the slope, which is as long as 1-10 ms (such an error shouldn't be acceptable). Except that the point of beginning needs not to be described: it simply is a mouse click or its simulation.
There are two more sites with the data about monitors: www.rtings.com and www.kitguru.net
Again, they don't say what they mean by the names of their measurements. They though clearly describe one: "Rise / Fall Time" (which is being measured between 10% and 90% points, and obviously represents the matrix response time (note that this data is also useless to us, because a smaller "matrix lag" doesn't guarantee for us that the "sending through computer->monitor cable + in-monitor data processing + sending data to matrix + matrix lag" sum will be smaller)).

Looking at the videos, I see that there yet are some bits of information.
In the beginning of first mentioned video, the measurement is shown as: mouse click - light sensor detection.
And I agree with you there (or you agree with me; or we both coincide 😊) that this method, which has too many additional variable lags, should not be used.
What could I say? Use a separate computer to set up Linux on it, and do Arduino stuff there (as I did: set up Arduino IDE; though the microcontrollers I'm using aren't Arduino). There you could inject/hack into open source video drivers, and catch the moment when sending of a frame data begins. Windows is really not fitting for that kind of job. The amount of efforts to be used on Linux is really lower. In fact, on Windows I simply dropped to do almost each thing (which required kernel-level) I wished to do, and if I didn't drop but yet try to do it, that costed me a lot of extra time, groundlessly.

Closed 2022-10-22.

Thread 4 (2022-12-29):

OSRTT Launcher Can't Display Correctly.

gomme1123, 2022-12-29:
**Describe the bug**
Run OSRTT Launcher and can't see the program display correctly.

**To Reproduce**
Steps to reproduce the behavior:
1. Run OSRTT Launcher V3.8
2. Can' adjust the application size and some portion of the program can't be seen.

**Expected behavior**
Fully display the program or enable application resize function.

**Screenshots**
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

**Desktop (please complete the following information):**
 - OS: Windows 10
 - Version V3.8
 - Display - NB dell latitude 5491, 1366x768, 60Hz, builtin panel.

**Additional context**
Tried on others desktop has same problem.

**Supporting Files**
N/A

andymanic, 2022-12-31:
To clarify a few things:
- With the screenshot you provided, only the text-wrapping seems to be off. The actual functions of the program should still work fine.
- I'm working on making Windows scaling not mess with the window and feature size as that's causing a lot of issues especially on Windows 11 right now. I'm hoping to have that sorted in the next update, but I'm having trouble recreating the 'broken' state to then test fixes.
Since I can't offer a solution right now I'll leave the issue open.

Vanri115, 2023-01-31:
Hi. I'm still having nearly same issue on v4.0 so I figured post some of screenshots if it may help.
My problem is not on home menu but with heatmaps.
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
this is with Windows 10 Home ver.22H2. not sure what else to address so if you could give me a direction I will dig in more.

andymanic, 2023-01-31:
> Hi. I'm still having nearly same issue on v4.0 so I figured post some of screenshots if it may help. My problem is not on home menu but with heatmaps. 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 this is with Windows 10 Home ver.22H2. not sure what else to address so if you could give me a direction I will dig in more.

Windows scaling is the bane of my life at the moment. It looks like it's only scaling in the vertical dimension though which is even weirder! If you can have a play with the scaling settings in Windows and see if that changes it's layout, that would be great. I'll keep hunting for how to stop Windows changing the aspect ratio of everything.

Vanri115, 2023-01-31:
okay, I tried these.
- disabling one monitor (since I use dual display)
- High DPI settings
- Changing around text, App scaling and resolution
no luck so far.

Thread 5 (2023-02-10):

Cant run either version 4.0, or 3.91

Axaion, 2023-02-10:
getting this error message
"The exception unknown software exception (0x0434352)
occured in the application at location 0x00007FFD65754F99."

andymanic, 2023-02-10:
It might be because I updated the .NET Framework version to 4.8.1 - here's the installer for that: https://dotnet.microsoft.com/en-us/download/dotnet-framework/net481
Otherwise it might be worth doing a fresh install of the software as I also updated some of the dependencies. Make sure to backup your results folder before deleting anything!
Let me know if either fix it and I'll close the issue.

Axaion, 2023-02-10:
Just installed both the dev and the normal version of 4.8.1, offline and web install, still the same error :|
also uninstalled and reinstalled osrtt afterwards and the error persists

andymanic, 2023-02-10:
Can you post a screenshot of the error?

Axaion, 2023-02-10:
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
here ya go

andymanic, 2023-02-10:
This isn't an error I can reproduce so it's hard to offer much support. Microsoft forums recommend running check disk and potentially running the repair .NET tool ([https://www.microsoft.com/en-gb/download/details.aspx?id=30135](https://www.microsoft.com/en-gb/download/details.aspx?id=30135)), and rebooting. Does V3.8 still work fine?

Axaion, 2023-02-10:
3.8 launches correctly, just tried installing it

andymanic, 2023-02-10:
Interesting. I have to assume it's an issue with .NET 4.8 on your machine then although I'm not sure what to recommend to fix that beyond the above steps.

Axaion, 2023-02-11:
Yeah i ran the checker too, and chkdsk, nothing seems to fix it .. strange - ill see if i can remember asking anyone else with it if they have the same issue later on!

chrisheinonen, 2023-02-27:
Also having the same issues with 3.91 and 4.0 and have updated to 4.81 runtimes. Here's output from the Windows Event Log:

`Faulting application name: OSRTT Launcher.exe, version: 4.0.0.0, time stamp: 0xec7822b7
Faulting module name: KERNELBASE.dll, version: 10.0.22621.1194, time stamp: 0xfaa44dd0
Exception code: 0xe0434352
Fault offset: 0x000000000009051c
Faulting process id: 0x0x95C
Faulting application start time: 0x0x1D94ADFBC4D377E
Faulting application path: C:\OSRTT Launcher\OSRTT Launcher.exe
Faulting module path: C:\Windows\System32\KERNELBASE.dll
Report Id: 9e291739-bd35-4c21-b42d-7917590d58fe
Faulting package full name:
Faulting package-relative application ID: `

andymanic, 2023-02-27:
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

Is that the only event log error that shows up? In theory there should be one listed as a ".NET Runtime" error too. I still have to assume it's a runtime error locally rather than a codebase issue, but I'm still stuck on what the fix is. Do you know if you have multiple versions of the .NET runtime installed? If so can you try uninstalling the older version to see if it's just a compatibility issue?

chrisheinonen, 2023-02-27:
>

This shows up as well:

> Faulting application name: OSRTT Launcher.exe, version: 4.0.0.0, time stamp: 0xec7822b7
Faulting module name: KERNELBASE.dll, version: 10.0.22621.1194, time stamp: 0xfaa44dd0
Exception code: 0xe0434352
Fault offset: 0x000000000009051c
Faulting process id: 0x0x95C
Faulting application start time: 0x0x1D94ADFBC4D377E
Faulting application path: C:\OSRTT Launcher\OSRTT Launcher.exe
Faulting module path: C:\Windows\System32\KERNELBASE.dll
Report Id: 9e291739-bd35-4c21-b42d-7917590d58fe
Faulting package full name:
Faulting package-relative application ID:

andymanic, 2023-02-27:
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

Interesting - it's failing at the auto updater.. Can you try replacing the contents of your C:\OSRTT Launcher folder with the attached files (except the OSRTT UE4 folder)? I've moved some files around which might be where your install is sticking. [OSRTT Update Files (V4.00).zip](https://github.com/andymanic/OSRTT/files/10845191/OSRTT.Update.Files.V4.00.zip)

chrisheinonen, 2023-02-27:
That fixed it, so I guess we know where the issue is now. Thanks!

andymanic, 2023-02-27:
Perfect, glad it's working! I'll update the release just in case. @Axaion can you try that too?

Axaion, 2023-03-08:
> Perfect, glad it's working! I'll update the release just in case. @Axaion can you try that too?

Sorry, took a bit to get back to you, yeah the linked files and manually overwriting works for me too.

andymanic, 2023-03-08:
No worries - glad that's sorted!

Closed 2023-03-08.

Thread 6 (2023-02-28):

Response time tests not run correctly?

edisonchan, 2023-02-28:
**What topic does your question cover? (ie end-user usage, C# code, C code, hardware)**
end-user usage.

**What's-up, doc?**
The OSRTT attched like below:
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

I received OSRTT yesterday and tested it on the AOC PD32M. The response time test seems to have failed to execute correctly. After clicking the response time test, a blank window will pop up, and there is no press key prompt on the OSRTT screen (if it is input delay test mode, it will prompt Press the button at the top).

After waiting for about two hours, the blank window is still there. Press ESC or Alt+F4 to close the blank window. You can see that the progress bar of OSRTT Launcher is running and then disappears quickly. Click to enter the test result folder, and the generated AOC PD32M The test results directory is empty and no result files are generated.

OS: Windows 11 fresh install
OSRTT Launcher version: 4.0
Windows screen scale mode: 100%.
GPU: NVIDIA RTX 3060(driver : 528.xx)

andymanic, 2023-02-28:
You do need to use the button to start any test - although I'll add a prompt to the firmware for the response time test to make that clear.

With that said, the PD32M is a Mini LED display that I don't think will work well with OSRTT. Give it a try anyway, but you might want to use the live view mode to see what I mean. It's backlight is PWM controlled at quite a low frequency (~500Hz if I remember correctly) which means the display won't output light while the backlight is off.

Closing the issue here.

edisonchan, 2023-03-01:
The OSRTT Pro show BACKLIGHT STROBING TEST CANCELLED after I pressed the button.

andymanic, 2023-03-01:
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
The Dell seems to be very slow on input latency, so the transition isn't being captured. Set the capture time to 200ms and it should work

Closed 2023-02-28.

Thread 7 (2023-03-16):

The app Windows not full and cannot be dragged to resize

imjunez, 2023-03-16:
**Describe the bug**
I finished installing the app with success, and I can run the program and it looks good to go. But the app windows is not full but it cannot be resized. Only the top left part is shown. It installed in 2 PCs and this happen only in one of them, which is an AIO MSI PRO mini PC with an Intel UHD.

**To Reproduce**
Steps to reproduce the behavior:
1. Run the program
2. Error shows

**Expected behavior**
It appears normally.

**Screenshots**
[If applicable, add screenshots to help explain your problem.](https://drive.google.com/file/d/1Sv5EMqDbFN8uvQJIRA_kyeSWH-CTAjLr/view?usp=sharing)

**Desktop (please complete the following information):**
 - OS: Windows 11
 - Version: I don't know. The version seems to be shown on the bottom part of the Windows, and I can't see it because the Windows only shows the top left part.
 - Display - Dual monitor ASUS VG28UQL1A, 4k 144Hz, DP, IPS and MSI MP273, FHD, 75Hz, HDMI, IPS
 -
**Additional context**
Add any other context about the problem here.

**Supporting Files**
Please dag & drop any relevant program-generated files, specifically the "RAW-OSRTT.csv" files when reporting incorrectly processed results.

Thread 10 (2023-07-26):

Custom game integration

WoodyPWX, 2023-07-26:
Hello there again,
I would like to measure input lag in our game. I can add a debug mode, reacting to mouse button click and showing a filled rectangle.
Can I use your launcher for this kind of measurement? Or do I need to read values directly and show them in my UI?
Regards,
Tomas

andymanic, 2023-07-26:
Hello again! So the response time tool isn't set up to do latency testing with external applications at the moment. It's certainly something that it could do with a bit of a firmware tweak. All the data processing is done in the desktop app so it's a little more complicated than just connecting via serial and displaying a result. I've actually been building the open source latency testing tool specifically for that ([project here](https://github.com/OSRTT/OSLTT)). Of course the hardware you currently have is capable of running that sort of test, so you are more than welcome to tweak the firmware and software to fit your needs. The main processing code isn't all that complicated especially for the latency test, so I'm sure you could incorporate that into your own software easy enough. I'd also be open to making a customised firmware and software for you on commission if that's of interest - although when factoring in the development time I'd argue it'd be more cost effective to just grab one of the latency tools instead.

WoodyPWX, 2023-07-26:
If I understand it correctly, the OSRTT launcher is now spawning an Unreal based app window over the selected monitor, so all I need is just to skip that if my own app (a game) is there already, waiting for mouse clicks, filling screen bellow the OSRTT device. That should be a fairly easy modification of the launcher app and hopefully no fw changes. I'm I right?

andymanic, 2023-07-27:
The latency test now uses my own DirectX code instead of the unreal app so you'd actually be better stepping back a few versions (looks like V3.4 was the last build before the DirectX stuff [here](https://github.com/andymanic/OSRTT/releases/tag/3.4)) and then replace the UE launcher and wait-for-exit with a sleep or something similar. The firmware for the latency test currently uses the arduino keyboard library as I found mouse capture wasn't as reliable, but it'd just be swapping "Keyboard.write("1");" with "Mouse.click(MOUSE_LEFT);" - in theory that'd be it at a basic level anyway.

WoodyPWX, 2023-07-27:
I will just add a check box to prevent any spawning and detect pressed "1" in our game, so it should minimize required changes.
Thanks for the info.

Closed 2023-07-27.

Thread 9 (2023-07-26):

FwFlashTool bricked my device

WoodyPWX, 2023-07-26:
Hello there,

After I flashed my new OSRTT PRO by the fw flash tool (4.3 package), it's no longer showing anything. Display is black, LED is red.
OSRTT Launcher sees the device connected, but reports these in a USB port where it worked fine before flashing:
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
I probably did something wrong in the flashing tool. I thought I should flash both "OSRTT" and "PRO", so I click both buttons. They both end up "successful". Flashing OSRTT is showing the text bellow.

Regards,
Tomas

OSRTT FW VERSION: 2.9
PRO FW VERSION: 1.4

Sketch uses 33720 bytes (6%) of program storage space. Maximum is 507904 bytes.

Device       : ATSAMD51x19
Version      : v1.1 [Arduino:XYZ] Jan 15 2022 11:54:42
Address      : 0x0
Pages        : 1024
Page Size    : 512 bytes
Total Size   : 512KB
Planes       : 1
Lock Regions : 32
Locked       : none
Security     : false
BOD          : false
BOR          : true
Write 35536 bytes to flash (70 pages)

[                              ] 0% (0/70 pages)
[===                           ] 11% (8/70 pages)
[======                        ] 22% (16/70 pages)
[==========                    ] 34% (24/70 pages)
[=============                 ] 45% (32/70 pages)
[=================             ] 57% (40/70 pages)
[====================          ] 68% (48/70 pages)
[========================      ] 80% (56/70 pages)
[===========================   ] 91% (64/70 pages)
[==============================] 100% (70/70 pages)
Done in 0.510 seconds
Verify 35536 bytes of flash

[=                             ] 4% (3/70 pages)
[=                             ] 5% (4/70 pages)
[==                            ] 7% (5/70 pages)
[==                            ] 8% (6/70 pages)
[===                           ] 10% (7/70 pages)
[===                           ] 11% (8/70 pages)
[===                           ] 12% (9/70 pages)
[====                          ] 14% (10/70 pages)
[====                          ] 15% (11/70 pages)
[=====                         ] 17% (12/70 pages)
[=====                         ] 18% (13/70 pages)
[======                        ] 20% (14/70 pages)
[======                        ] 21% (15/70 pages)
[======                        ] 22% (16/70 pages)
[=======                       ] 24% (17/70 pages)
[=======                       ] 25% (18/70 pages)
[========                      ] 27% (19/70 pages)
[========                      ] 28% (20/70 pages)
[=========                     ] 30% (21/70 pages)
[=========                     ] 31% (22/70 pages)
[=========                     ] 32% (23/70 pages)
[==========                    ] 34% (24/70 pages)
[==========                    ] 35% (25/70 pages)
[===========                   ] 37% (26/70 pages)
[===========                   ] 38% (27/70 pages)
[============                  ] 40% (28/70 pages)
[============                  ] 41% (29/70 pages)
[============                  ] 42% (30/70 pages)
[=============                 ] 44% (31/70 pages)
[=============                 ] 45% (32/70 pages)
[==============                ] 47% (33/70 pages)
[==============                ] 48% (34/70 pages)
[===============               ] 50% (35/70 pages)
[===============               ] 51% (36/70 pages)
[===============               ] 52% (37/70 pages)
[================              ] 54% (38/70 pages)
[================              ] 55% (39/70 pages)
[=================             ] 57% (40/70 pages)
[=================             ] 58% (41/70 pages)
[==================            ] 60% (42/70 pages)
[==================            ] 61% (43/70 pages)
[==================            ] 62% (44/70 pages)
[===================           ] 64% (45/70 pages)
[===================           ] 65% (46/70 pages)
[====================          ] 67% (47/70 pages)
[====================          ] 68% (48/70 pages)
[=====================         ] 70% (49/70 pages)
[=====================         ] 71% (50/70 pages)
[=====================         ] 72% (51/70 pages)
[======================        ] 74% (52/70 pages)
[======================        ] 75% (53/70 pages)
[=======================       ] 77% (54/70 pages)
[=======================       ] 78% (55/70 pages)
[========================      ] 80% (56/70 pages)
[========================      ] 81% (57/70 pages)
[========================      ] 82% (58/70 pages)
[=========================     ] 84% (59/70 pages)
[=========================     ] 85% (60/70 pages)
[==========================    ] 87% (61/70 pages)
[==========================    ] 88% (62/70 pages)
[===========================   ] 90% (63/70 pages)
[===========================   ] 91% (64/70 pages)
[===========================   ] 92% (65/70 pages)
[============================  ] 94% (66/70 pages)
[============================  ] 95% (67/70 pages)
[============================= ] 97% (68/70 pages)
[============================= ] 98% (69/70 pages)
[==============================] 100% (70/70 pages)
Verify successful
Done in 0.169 seconds

andymanic, 2023-07-26:
Hi there - so I think what's happened is it has flashed the non-pro device firmware, hence the display not showing anything and you're getting the USB voltage errors that are only present on the original device. Can you try clicking just the "flash pro" button (with the main OSRTT Launcher program closed) and see if that restores it? If it doesn't, please do copy the output like you've done here so I can confirm what's wrong.

WoodyPWX, 2023-07-26:
I was trying that before, but "PRO" button flashing is not outputting anything. All I get is
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

WoodyPWX, 2023-07-26:
The new flash tool is about 1KB bigger, but it behaves exactly the same. No text output while flashing PRO and then the "updated successfully" button. Device still not fixed. Regarding my forced flashing, I will not use that again. At least you know the tool should be more foolproof :)

andymanic, 2023-07-26:
Ok. Can you disconnect and reconnect the device? Is the LED inside still red? If it is, I suspect you might need to open the unit up to press the reset button on the microcontroller board. It's two 2.5mm Allen/hex key screws on the bottom and the reset button is basically in the middle of the board. The board should be plugged in and you might need to press the reset button twice in quick succession until the built in LED is either green or purple. I'm hopeful unplugging and reconnecting will solve it though!

WoodyPWX, 2023-07-26:
Reconnecting didn't help, but after I opened the unit up, I realized the LED color is not red but actually purple. Double press of the reset button makes it red and then immediately green and the Launcher is not complaining anymore. The display is still black though and after disconnecting from USB and reconnecting, the LED is again purple, requiring reset.

andymanic, 2023-07-26:
Ah ok, that's good. The board is definitely in a recoverable state. Can you check that there's a file called "OSRTT_Pro_Code_1.5.ino.bin" in "C:\OSRTT Launcher\arduinoCLI"?

If there is, can you also check what COM port the device is using - you can see that either in Device Manager under "Ports", or even better open powershell and run "& "C:\OSRTT Launcher\arduinoCLI\arduino-cli.exe" board list"

If there isn't, you can grab it from the repo and place it in that folder - [file](https://github.com/andymanic/OSRTT/releases/download/4.3/OSRTT_Pro_Code_1.5.ino.bin)

Then run "& "C:\OSRTT Launcher\arduinoCLI\arduino-cli.exe" upload --port COM3 --fqbn adafruit:samd:adafruit_itsybitsy_m4 -i "C:\OSRTT Launcher\arduinoCLI\OSRTT_Pro_Code_1.5.ino.bin""

That should flash the board manually and give you the full output (and therefore any error messages).

Closed 2023-07-26.

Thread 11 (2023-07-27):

Running launcher from GitHub code

WoodyPWX, 2023-07-27:
Hello there,

I'm using OSRTT source code from GitHub, main branch.
If I open OSRTT Launcher.sln in both VS2019 (or VS2022) and compile, it fails on this:

Build started...
1>------ Build started: Project: OSRTT Launcher, Configuration: Debug Any CPU ------
1>C:\Program Files\Microsoft Visual Studio\2022\Community\MSBuild\Current\Bin\amd64\Microsoft.Common.CurrentVersion.targets(3476,5): error MSB3322: Unable to get MD5 checksum for the key file "OSRTT Launcher_1_TemporaryKey.pfx". Could not find file 'C:\Temp\OSRTT\OSRTT Launcher\OSRTT Launcher\OSRTT Launcher_1_TemporaryKey.pfx'.
========== Build: 0 succeeded, 1 failed, 0 up-to-date, 0 skipped ==========

Solution Explorer is showing these .pfx files missing:
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

If I disable this signing:
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

I can compile and start the launcher, but it never detects my OSRTT PRO unit, unlike your prebuilt version:
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

The VS output window is spamming: The system cannot find the path specified.

Regards,
Tomas

WoodyPWX, 2023-07-27:
I think it's trying to run this:
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
so I've set correct working directory for debugging into directory with your downloaded build, including that file, so it's all good now :)

andymanic, 2023-07-27:
You beat me to it! It uses the arduino CLI to detect which COM port to connect with so needs the program in the correct directory. As for the key files, I forgot they'd be linked in the SLN. Disabling signing or generating your own key is the fix and again you've beat me there.

WoodyPWX, 2023-07-28:
Thanks for the clarification!

Closed 2023-07-28.

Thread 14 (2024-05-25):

It is hoped that the test results can retain two decimal places.

edisonchan, 2024-05-25:
**Is your feature request related to a problem? Please describe.**
The test results currently being recorded are rounded to one decimal place.

**Describe the solution you'd like**
It would be great if an option could be added to retain two decimal places, or if the program’s default could be changed to retain two decimal places.

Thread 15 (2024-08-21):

Crash - Illegal characters in path.

chrisheinonen, 2024-08-21:
**Describe the bug**
New install on a new laptop, has updated to 4.8.5. As soon as I click on Start Response Time Testing I get a pop-up of "Unexpected Error: Illegal Characters in Path"

**To Reproduce**
Steps to reproduce the behavior:
1. Click 'Start Response Time Testing'
2. Get error

**Expected behavior**
Response time testing should start

**Screenshots**
NA

**Desktop (please complete the following information):**
 - OS: Windows 11 ARM
 - Version 4.8.5
 - Display - 2880x1800, 60Hz, no HDR, 200% scaling

**Additional context**
Add any other context about the problem here.

**Supporting Files**
[OSRTT Crashes.evtx.zip](https://github.com/user-attachments/files/16700680/OSRTT.Crashes.evtx.zip)

Windows Event Viewer events attached

andymanic, 2024-08-21:
Hi Chris, thanks for the bug report! I am yet to use Windows 11 ARM so I have to assume it's something going on there - the crash seems to be from when the program tries to create a folder for the results - can you let me know what the monitor name reports as in the main window, and if you are including any special overdrive mode text?

chrisheinonen, 2024-08-21:
The monitor name reports as "134WT1" and it crashes before the pop-up window that lets me select an Overdrive Mode or enter a custom one.

chrisheinonen, 2024-08-21:
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

andymanic, 2024-08-22:
I'm surprised this is the first time that has happened! It seems the WindowsAPI I use for getting the monitor name is adding a new line to the name, which is breaking the search function. I'll fix that and send over a new version for you and include the fix in all future releases too.

andymanic, 2024-08-22:
[OSRTT Launcher.zip](https://github.com/user-attachments/files/16707778/OSRTT.Launcher.zip)
This should be a fix for that - please do let me know if it doesn't work as I am unable to replicate the issue locally so can't test to make sure!

chrisheinonen, 2024-08-22:
"Object reference not set to an instance of an object"

Event Viewer files attached. This time the Overdrive Mode window does launch, but as soon as it does the above error occurs. This didn't happen on other ARM laptops so must be something strange about this one.

[OSRTT Crashes 2.zip](https://github.com/user-attachments/files/16714190/OSRTT.Crashes.2.zip)

andymanic, 2024-08-22:
[OSRTT Launcher.zip](https://github.com/user-attachments/files/16714242/OSRTT.Launcher.zip)
I suspect my fix didn't quite get it - here's a version with that message box put back in but the remove new line still there. Can you show me what the message box says again? I'm trying to work out how I can replicate the issue to test it locally but I'm drawing a blank!

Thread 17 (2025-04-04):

Incompatible Firmware Version

Vanri115, 2025-04-04:
Hi, I've been using ver4.85, and when I open up the OSRTT Launcher it alwasy gives me an pop up saying "Incompatible Firmwar Version Warning - the FPS limit feature won't work with you current firmware version".

So I try to go Debugging Tools -> Update Device Firmware, it gives me nothing.
My Current Firmware version is V1.4. Is it outdated?
How can I update my firmware version?

Also after I finish Response time testing, it won't give me heatmap but crashes.
It gives me an popup saying "Unexpected Error - Program Closing Object reference not set to an instance of an object"

I'm on Win11.

Thanks!

andymanic, 2025-04-04:
Hi there! V1.4 is old, we're on V2.0 now! With the tool connected can you open the OSRTTFirmwareFlashTool.exe in C:/OSRTT Launcher and hit "Flash Pro" (assuming you're using an OSRTT Pro/Pro CS anyway) and tell me what it says?

Vanri115, 2025-04-05:
Hi, Thanks for the solution!
I updated it to v2.0 and fps limit warning has disappeared.
But I’m still getting Object Reference error and the program shut it down after the test, any idea on that?

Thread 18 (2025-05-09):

How tu Build  Why do I report an error when I compile through the IDE? Can I only use Launch?

HeTuii1, 2025-05-09:
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
# Why do I report an error when I compile through the IDE? Can I only use Launch?

C:\Users\TP\Downloads\OSRTT.Update.Files.V4.85\arduinoCLI\OSRTT_Full_Code\OSRTT_Full_Code.ino: In function 'void ADC_Clocks()':
C:\Users\TP\Downloads\OSRTT.Update.Files.V4.85\arduinoCLI\OSRTT_Full_Code\OSRTT_Full_Code.ino:49:4: error: 'MCLK' was not declared in this scope
    MCLK->APBDMASK.bit.ADC0_ = 1;
    ^
C:\Users\TP\Downloads\OSRTT.Update.Files.V4.85\arduinoCLI\OSRTT_Full_Code\OSRTT_Full_Code.ino:52:10: error: 'struct Gclk' has no member named 'PCHCTRL'
    GCLK->PCHCTRL[ADC0_GCLK_ID].reg = GCLK_PCHCTRL_GEN_GCLK1_Val | (1 << GCLK_PCHCTRL_CHEN_Pos); // enable gen clock 1 as source for ADC channel
          ^
C:\Users\TP\Downloads\OSRTT.Update.Files.V4.85\arduinoCLI\OSRTT_Full_Code\OSRTT_Full_Code.ino:52:18: error: 'ADC0_GCLK_ID' was not declared in this scope
    GCLK->PCHCTRL[ADC0_GCLK_ID].reg = GCLK_PCHCTRL_GEN_GCLK1_Val | (1 << GCLK_PCHCTRL_CHEN_Pos); // enable gen clock 1 as source for ADC channel
                  ^
C:\Users\TP\Downloads\OSRTT.Update.Files.V4.85\arduinoCLI\OSRTT_Full_Code\OSRTT_Full_Code.ino:52:38: error: 'GCLK_PCHCTRL_GEN_GCLK1_Val' was not declared in this scope
    GCLK->PCHCTRL[ADC0_GCLK_ID].reg = GCLK_PCHCTRL_GEN_GCLK1_Val | (1 << GCLK_PCHCTRL_CHEN_Pos); // enable gen clock 1 as source for ADC channel
                                      ^
C:\Users\TP\Downloads\OSRTT.Update.Files.V4.85\arduinoCLI\OSRTT_Full_Code\OSRTT_Full_Code.ino:52:73: error: 'GCLK_PCHCTRL_CHEN_Pos' was not declared in this scope
    GCLK->PCHCTRL[ADC0_GCLK_ID].reg = GCLK_PCHCTRL_GEN_GCLK1_Val | (1 << GCLK_PCHCTRL_CHEN_Pos); // enable gen clock 1 as source for ADC channel
                                                                         ^
C:\Users\TP\Downloads\OSRTT.Update.Files.V4.85\arduinoCLI\OSRTT_Full_Code\OSRTT_Full_Code.ino:53:10: error: 'struct Gclk' has no member named 'PCHCTRL'
    GCLK->PCHCTRL[ADC1_GCLK_ID].reg = GCLK_PCHCTRL_GEN_GCLK1_Val | (1 << GCLK_PCHCTRL_CHEN_Pos); // enable gen clock 1 as source for ADC channel
          ^
C:\Users\TP\Downloads\OSRTT.Update.Files.V4.85\arduinoCLI\OSRTT_Full_Code\OSRTT_Full_Code.ino:53:18: error: 'ADC1_GCLK_ID' was not declared in this scope
    GCLK->PCHCTRL[ADC1_GCLK_ID].reg = GCLK_PCHCTRL_GEN_GCLK1_Val | (1 << GCLK_PCHCTRL_CHEN_Pos); // enable gen clock 1 as source for ADC channel
                  ^
C:\Users\TP\Downloads\OSRTT.Update.Files.V4.85\arduinoCLI\OSRTT_Full_Code\OSRTT_Full_Code.ino: In function 'void ADC_Init(Adc*)':
C:\Users\TP\Downloads\OSRTT.Update.Files.V4.85\arduinoCLI\OSRTT_Full_Code\OSRTT_Full_Code.ino:62:23: error: 'volatile struct ADC_INPUTCTRL_Type::<anonymous>' has no member named 'DIFFMODE'
   ADCx->INPUTCTRL.bit.DIFFMODE = 0;
                       ^
C:\Users\TP\Downloads\OSRTT.Update.Files.V4.85\arduinoCLI\OSRTT_Full_Code\OSRTT_Full_Code.ino:63:16: error: 'struct Adc' has no member named 'SYNCBUSY'
   while( ADCx->SYNCBUSY.reg & ADC_SYNCBUSY_INPUTCTRL );
                ^
C:\Users\TP\Downloads\OSRTT.Update.Files.V4.85\arduinoCLI\OSRTT_Full_Code\OSRTT_Full_Code.ino:63:31: error: 'ADC_SYNCBUSY_INPUTCTRL' was not declared in this scope
   while( ADCx->SYNCBUSY.reg & ADC_SYNCBUSY_INPUTCTRL );
                               ^
C:\Users\TP\Downloads\OSRTT.Update.Files.V4.85\arduinoCLI\OSRTT_Full_Code\OSRTT_Full_Code.ino:66:16: error: 'struct Adc' has no member named 'SYNCBUSY'
   while( ADCx->SYNCBUSY.reg & ADC_SYNCBUSY_INPUTCTRL );
                ^
C:\Users\TP\Downloads\OSRTT.Update.Files.V4.85\arduinoCLI\OSRTT_Full_Code\OSRTT_Full_Code.ino:66:31: error: 'ADC_SYNCBUSY_INPUTCTRL' was not declared in this scope
   while( ADCx->SYNCBUSY.reg & ADC_SYNCBUSY_INPUTCTRL );
                               ^
C:\Users\TP\Downloads\OSRTT.Update.Files.V4.85\arduinoCLI\OSRTT_Full_Code\OSRTT_Full_Code.ino:69:19: error: 'volatile struct ADC_CTRLA_Type::<anonymous>' has no member named 'PRESCALER'
   ADCx->CTRLA.bit.PRESCALER = ADC_CTRLA_PRESCALER_DIV4_Val;
                   ^
C:\Users\TP\Downloads\OSRTT.Update.Files.V4.85\arduinoCLI\OSRTT_Full_Code\OSRTT_Full_Code.ino:69:31: error: 'ADC_CTRLA_PRESCALER_DIV4_Val' was not declared in this scope
   ADCx->CTRLA.bit.PRESCALER = ADC_CTRLA_PRESCALER_DIV4_Val;
                               ^
C:\Users\TP\Downloads\OSRTT.Update.Files.V4.85\arduinoCLI\OSRTT_Full_Code\OSRTT_Full_Code.ino:78:15: error: 'struct Adc' has no member named 'SYNCBUSY'
   while(ADCx->SYNCBUSY.reg & ADC_SYNCBUSY_CTRLB);
               ^
C:\Users\TP\Downloads\OSRTT.Update.Files.V4.85\arduinoCLI\OSRTT_Full_Code\OSRTT_Full_Code.ino:78:30: error: 'ADC_SYNCBUSY_CTRLB' was not declared in this scope
   while(ADCx->SYNCBUSY.reg & ADC_SYNCBUSY_CTRLB);
                              ^
C:\Users\TP\Downloads\OSRTT.Update.Files.V4.85\arduinoCLI\OSRTT_Full_Code\OSRTT_Full_Code.ino:84:15: error: 'struct Adc' has no member named 'SYNCBUSY'
   while(ADCx->SYNCBUSY.reg & ADC_SYNCBUSY_SAMPCTRL);
               ^
C:\Users\TP\Downloads\OSRTT.Update.Files.V4.85\arduinoCLI\OSRTT_Full_Code\OSRTT_Full_Code.ino:84:30: error: 'ADC_SYNCBUSY_SAMPCTRL' was not declared in this scope
   while(ADCx->SYNCBUSY.reg & ADC_SYNCBUSY_SAMPCTRL);
                              ^
C:\Users\TP\Downloads\OSRTT.Update.Files.V4.85\arduinoCLI\OSRTT_Full_Code\OSRTT_Full_Code.ino:90:15: error: 'struct Adc' has no member named 'SYNCBUSY'
   while(ADCx->SYNCBUSY.reg & ADC_SYNCBUSY_AVGCTRL)
               ^
C:\Users\TP\Downloads\OSRTT.Update.Files.V4.85\arduinoCLI\OSRTT_Full_Code\OSRTT_Full_Code.ino:90:30: error: 'ADC_SYNCBUSY_AVGCTRL' was not declared in this scope
   while(ADCx->SYNCBUSY.reg & ADC_SYNCBUSY_AVGCTRL)
                              ^
C:\Users\TP\Downloads\OSRTT.Update.Files.V4.85\arduinoCLI\OSRTT_Full_Code\OSRTT_Full_Code.ino:100:15: error: 'struct Adc' has no member named 'SYNCBUSY'
   while(ADCx->SYNCBUSY.bit.ENABLE);
               ^
C:\Users\TP\Downloads\OSRTT.Update.Files.V4.85\arduinoCLI\OSRTT_Full_Code\OSRTT_Full_Code.ino: In function 'void ADCHighSpeedMode(int)':
C:\Users\TP\Downloads\OSRTT.Update.Files.V4.85\arduinoCLI\OSRTT_Full_Code\OSRTT_Full_Code.ino:108:5: error: 'ADC0' was not declared in this scope
     ADC0->AVGCTRL.reg = ADC_AVGCTRL_SAMPLENUM_4_Val;
     ^
C:\Users\TP\Downloads\OSRTT.Update.Files.V4.85\arduinoCLI\OSRTT_Full_Code\OSRTT_Full_Code.ino:112:5: error: 'ADC0' was not declared in this scope
     ADC0->AVGCTRL.reg = ADC_AVGCTRL_SAMPLENUM_16_Val;
     ^
C:\Users\TP\Downloads\OSRTT.Update.Files.V4.85\arduinoCLI\OSRTT_Full_Code\OSRTT_Full_Code.ino:115:9: error: 'ADC0' was not declared in this scope
   while(ADC0->SYNCBUSY.reg & ADC_SYNCBUSY_AVGCTRL);
         ^
C:\Users\TP\Downloads\OSRTT.Update.Files.V4.85\arduinoCLI\OSRTT_Full_Code\OSRTT_Full_Code.ino:115:30: error: 'ADC_SYNCBUSY_AVGCTRL' was not declared in this scope
   while(ADC0->SYNCBUSY.reg & ADC_SYNCBUSY_AVGCTRL);
                              ^
C:\Users\TP\Downloads\OSRTT.Update.Files.V4.85\arduinoCLI\OSRTT_Full_Code\OSRTT_Full_Code.ino: In function 'int checkLightLevel()':
C:\Users\TP\Downloads\OSRTT.Update.Files.V4.85\arduinoCLI\OSRTT_Full_Code\OSRTT_Full_Code.ino:125:3: error: 'ADC0' was not declared in this scope
   ADC0->SWTRIG.bit.START = 1; //Start ADC
   ^
C:\Users\TP\Downloads\OSRTT.Update.Files.V4.85\arduinoCLI\OSRTT_Full_Code\OSRTT_Full_Code.ino: In function 'void runADC(int, int, char, String)':
C:\Users\TP\Downloads\OSRTT.Update.Files.V4.85\arduinoCLI\OSRTT_Full_Code\OSRTT_Full_Code.ino:189:7: error: 'ADC0' was not declared in this scope
       ADC0->SWTRIG.bit.START = 1; //Start ADC
       ^
C:\Users\TP\Downloads\OSRTT.Update.Files.V4.85\arduinoCLI\OSRTT_Full_Code\OSRTT_Full_Code.ino:196:5: error: 'ADC0' was not declared in this scope
     ADC0->SWTRIG.bit.START = 0; //Stop ADC
     ^
C:\Users\TP\Downloads\OSRTT.Update.Files.V4.85\arduinoCLI\OSRTT_Full_Code\OSRTT_Full_Code.ino: In function 'int checkUSBVoltage(int)':
C:\Users\TP\Downloads\OSRTT.Update.Files.V4.85\arduinoCLI\OSRTT_Full_Code\OSRTT_Full_Code.ino:241:5: error: 'ADC1' was not declared in this scope
     ADC1->SWTRIG.bit.START = 1; //Start ADC1
     ^
C:\Users\TP\Downloads\OSRTT.Update.Files.V4.85\arduinoCLI\OSRTT_Full_Code\OSRTT_Full_Code.ino:254:3: error: 'ADC1' was not declared in this scope
   ADC1->SWTRIG.bit.START = 0; //Stop ADC
   ^
C:\Users\TP\Downloads\OSRTT.Update.Files.V4.85\arduinoCLI\OSRTT_Full_Code\OSRTT_Full_Code.ino: In function 'void runInputLagTest(int)':
C:\Users\TP\Downloads\OSRTT.Update.Files.V4.85\arduinoCLI\OSRTT_Full_Code\OSRTT_Full_Code.ino:304:5: error: 'ADC0' was not declared in this scope
     ADC0->SWTRIG.bit.START = 1;
     ^
C:\Users\TP\Downloads\OSRTT.Update.Files.V4.85\arduinoCLI\OSRTT_Full_Code\OSRTT_Full_Code.ino:310:3: error: 'ADC0' was not declared in this scope
   ADC0->SWTRIG.bit.START = 0;
   ^
C:\Users\TP\Downloads\OSRTT.Update.Files.V4.85\arduinoCLI\OSRTT_Full_Code\OSRTT_Full_Code.ino: In function 'void setup()':
C:\Users\TP\Downloads\OSRTT.Update.Files.V4.85\arduinoCLI\OSRTT_Full_Code\OSRTT_Full_Code.ino:379:12: error: 'ADC0' was not declared in this scope
   ADC_Init(ADC0); //Initialise ADC0
            ^
C:\Users\TP\Downloads\OSRTT.Update.Files.V4.85\arduinoCLI\OSRTT_Full_Code\OSRTT_Full_Code.ino:380:12: error: 'ADC1' was not declared in this scope
   ADC_Init(ADC1); //Initialise ADC1
            ^
C:\Users\TP\Downloads\OSRTT.Update.Files.V4.85\arduinoCLI\OSRTT_Full_Code\OSRTT_Full_Code.ino: In function 'void loop()':
C:\Users\TP\Downloads\OSRTT.Update.Files.V4.85\arduinoCLI\OSRTT_Full_Code\OSRTT_Full_Code.ino:422:9: error: 'ADC0' was not declared in this scope
         ADC0->SWTRIG.bit.START = 1; //Start ADC
         ^
C:\Users\TP\Downloads\OSRTT.Update.Files.V4.85\arduinoCLI\OSRTT_Full_Code\OSRTT_Full_Code.ino:471:11: error: 'ADC0' was not declared in this scope
           ADC0->SWTRIG.bit.START = 1; //Start ADC
           ^
C:\Users\TP\Downloads\OSRTT.Update.Files.V4.85\arduinoCLI\OSRTT_Full_Code\OSRTT_Full_Code.ino:851:15: error: 'ADC0' was not declared in this scope
               ADC0->SWTRIG.bit.START = 1; //Start ADC
               ^
Multiple libraries were found for "Keyboard.h"
  Used: C:\OSRTT Launcher\arduinoCLI\libraries\Keyboard
  Not used: C:\Users\TP\AppData\Local\Arduino15\libraries\Keyboard
Multiple libraries were found for "Mouse.h"
  Used: C:\OSRTT Launcher\arduinoCLI\libraries\Mouse
  Not used: C:\Users\TP\AppData\Local\Arduino15\libraries\Mouse
exit status 1

Compilation error: 'MCLK' was not declared in this scope

andymanic, 2025-05-09:
Hi there, the sketch is written for the Adafruit ItsyBitsy M4 so you'll need that board and to select it in the board menu before it will compile. It's also specifically designed for the original OSRTT circuit/PCB, so you'll need that to make it do much more than connect over serial.

HeTuii1, 2025-05-10:
> 您好，这个 sketch 是为 Adafruit ItsyBitsy M4 编写的，所以您需要这块开发板，并在开发板菜单中选中它才能编译。它也是专门为原始 OSRTT 电路/PCB 设计的，所以您需要它来让它完成比串行连接更多的功能。

HeTuii1, 2025-05-10:
Do I have to own this board to compile? What if I just want to compile it and generate firmware or something?

andymanic, 2025-05-10:
You don't have to own the board to compile it, you just need to install the adafruit SAMD board's core in the arduino ide then select it in the boards list. [https://learn.adafruit.com/introducing-adafruit-itsybitsy-m4/setup](https://learn.adafruit.com/introducing-adafruit-itsybitsy-m4/setup)

HeTuii1, 2025-05-10:
> You don't have to own the board to compile it, you just need to install the adafruit SAMD board's core in the arduino ide then select it in the boards list. https://learn.adafruit.com/introducing-adafruit-itsybitsy-m4/setup

OSRTT_Full_Code:4:10: fatal error: ArduinoUniqueID.h: No such file or directory
    4 | #include <ArduinoUniqueID.h>
      |          ^~~~~~~~~~~~~~~~~~~
compilation terminated.
exit status 1
ArduinoUniqueID.h: No such file or directory

Closed 2025-05-10.

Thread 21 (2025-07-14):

Am I doing the OSRTT test right?

LordRaiden1, 2025-07-14:
Hi. I want to ask you if I'm doing tests right. Here is an example of test I run and the result screen. Is this a valid result, if not what am I missing? Thank you for your time.

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

andymanic, 2025-07-14:
Personally I test with VSync on and the framerate limit at 1000, but otherwise yeah looks fine. The undershoot is a little weird, you'll want to hit the "Raw Data Graphs" button at the top there to view the raw data in graph form and see what's going on. Also, if you want me to verify issues or data, I need the data to do so. Please include a zip file of the test data folder you want me to look at in future.

andymanic, 2025-07-16:
The data looks a lot better, although I'd recommend increasing the capture time to 150 milliseconds as at 60hz it's running a little slow. There's also an interesting dip on the MO32U at frame time, although being an OLED that's kind of expected. I should also mention that for OLEDs with adaptive brightness limiters, you'll want to hit ALT + ENTER when the UE4 test window pops up to make it windowed so you can resize it to just fit under the tool to minimally affect the brightness during the test.

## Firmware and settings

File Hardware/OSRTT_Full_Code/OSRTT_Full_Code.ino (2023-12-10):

#include <Keyboard.h>
#include <Mouse.h>
#include <SPI.h>
#include <ArduinoUniqueID.h>
#define INPUT_SIZE 8

//Test values
// These are the RGB values it tests with
int RGBArr[] = {0,51,102,153,204,255};
// These are the keys that correspond with the above values
char Keys[] = {'q','z','s','e','c','f'};
// Ideally I'd pair these together in an array of key/value pairs but this works for now. 
// These are the RGB values it tests with
int OldRGBArr[] = {0,26,51,77,102,128,153,179,204,230,255};
// These are the keys that correspond with the above values
char OldKeys[] = {'q','a','z','w','s','x','e','d','c','r','f'};
// Ideally I'd pair these together in an array of key/value pairs but this works for now. 
int extGammaArr[] = {0,17,34,51,68,85,102,119,136,153,170,187,204,221,238,255};
char extGammaKeys[] = {'q','y','h','z','n','u','s','j','m','e','i','k','c','o','l','f',};

//ADC values
unsigned long curr_time = micros();
uint32_t sample_count = 0;
//50ms sample time default
unsigned long samplingTime = 50000;
uint16_t adcBuff[16000];

//Button values
int buttonState = 0;
const int buttonPin = 2;

//Digital Potentiometer values (SPI)
byte address = 0x02;
int CS = 10;
SPISettings settingsA(10000000, MSBFIRST, SPI_MODE0);

//Serial connection values
bool connected = false;
int boardType = 0;
String firmware = "3.2";
int testRuns = 4;
bool vsync = true;
bool extendedGamma = true;
int fpsLimit = '1';
int USBV = 0;

void ADC_Clocks() // Turns out to be superfluous as Adafruit wiring.c already sets these clocks. Keeping for now to guarantee settings are set.
{
   MCLK->APBDMASK.bit.ADC0_ = 1;
   MCLK->APBDMASK.bit.ADC1_ = 1;
   //Use GCLK1, channel it for ADC0, select DFLL(48MHz) as source and make sure no divider is selected
   GCLK->PCHCTRL[ADC0_GCLK_ID].reg = GCLK_PCHCTRL_GEN_GCLK1_Val | (1 << GCLK_PCHCTRL_CHEN_Pos); // enable gen clock 1 as source for ADC channel
   GCLK->PCHCTRL[ADC1_GCLK_ID].reg = GCLK_PCHCTRL_GEN_GCLK1_Val | (1 << GCLK_PCHCTRL_CHEN_Pos); // enable gen clock 1 as source for ADC channel
}

void ADC_Init(Adc *ADCx)
{
   //////////////////////////////////////////////////////////////////////////
   //     Initialise ADC - Defaults set to 16bit results @ ~129KSPS        //
   //////////////////////////////////////////////////////////////////////////

  ADCx->INPUTCTRL.bit.DIFFMODE = 0;
  while( ADCx->SYNCBUSY.reg & ADC_SYNCBUSY_INPUTCTRL );
  
  ADCx->INPUTCTRL.bit.MUXPOS = 0;
  while( ADCx->SYNCBUSY.reg & ADC_SYNCBUSY_INPUTCTRL );

  //Divide 8MHz clock - default DIV4 = 2MHz ADC clock
  ADCx->CTRLA.bit.PRESCALER = ADC_CTRLA_PRESCALER_DIV4_Val;

  //Choose 16-bit resolution to oversample - use 12BIT_VAL for 1MSPS
  ADCx->CTRLB.bit.RESSEL = ADC_CTRLB_RESSEL_16BIT_Val;
  //Ensuring freerun is activated
  //Freerun means it automatically reads the next result rather than waiting for this code to tell it to check.
  ADCx->CTRLB.bit.FREERUN = 1;

  //waiting for synchronisation
  while(ADCx->SYNCBUSY.reg & ADC_SYNCBUSY_CTRLB);

  //Sampletime set to 0
  ADCx->SAMPCTRL.reg = 0;

  //Waiting for synchronisation
  while(ADCx->SYNCBUSY.reg & ADC_SYNCBUSY_SAMPCTRL);

  // Accumulate samples to gain higher final result precision  
  ADCx->AVGCTRL.reg = ADC_AVGCTRL_SAMPLENUM_16_Val; //Sample 16 values for 16 bit output, 8 for 15 bit, 4 for 14 bit

  //Wait for synchronisation
  while(ADCx->SYNCBUSY.reg & ADC_SYNCBUSY_AVGCTRL)

  //Select VDDANA (3.3V chip supply voltage as reference)
  ADCx->REFCTRL.reg = ADC_REFCTRL_REFSEL_INTVCC1;

  //Enable ADC
  ADCx->SWTRIG.bit.START = 1;
  ADCx->CTRLA.bit.ENABLE = 1;

  //wait for ADC to be ready
  while(ADCx->SYNCBUSY.bit.ENABLE);
}

void ADCHighSpeedMode(int highSpeed)
{
  if (highSpeed == 1)
  {
    // Swap to just 4 sample average for 250KSPS instead of 62,500
    ADC0->AVGCTRL.reg = ADC_AVGCTRL_SAMPLENUM_4_Val; 
  }
  else
  {
    ADC0->AVGCTRL.reg = ADC_AVGCTRL_SAMPLENUM_16_Val;
  }
  //Wait for synchronisation
  while(ADC0->SYNCBUSY.reg & ADC_SYNCBUSY_AVGCTRL);
}

int checkLightLevel() // Check light level & modulate potentiometer value 
{
  Keyboard.write('f');
  delay(400);
  int potValue = 160;
  digitalPotWrite(potValue);
  delay(200);
  ADC0->SWTRIG.bit.START = 1; //Start ADC 
  while(!ADC0->INTFLAG.bit.RESRDY); //wait for ADC to have a new value
  int value = ADC0->RESULT.reg;
  while(value <= 63000 || value >= 64000)
  {
    ADC0->SWTRIG.bit.START = 1; //Start ADC 
    while(!ADC0->INTFLAG.bit.RESRDY); //wait for ADC to have a new value
    value = ADC0->RESULT.reg;
    if (value >= 64000)
    {
      //Set digital pot to decrease voltage
      potValue -= 1; //or the other way...
      digitalPotWrite(potValue);
      Serial.print("Value: ");
      Serial.print(value);
      Serial.print(", Pot Value: ");
      Serial.println(potValue);
    }
    else if (value <= 63000)
    {
      //Set digital pot to increase volt
      potValue += 1; //or the other way...
      digitalPotWrite(potValue);
      Serial.print("Value: ");
      Serial.print(value);
      Serial.print(", Pot Value: ");
      Serial.println(potValue);
    }
    else
    {
      break;  
    }
    if (potValue <= 159 || potValue == 255)
    {
      Serial.print("TEST CANCELLED - LIGHT LEVEL:");
      Serial.println(value);
      Keyboard.write('q');
      return 0;
      break; //not needed?  
    }
    delay(20);
  }
  Keyboard.write('q');
  delay(400);
  return 1;
}

void runADC(int curr, int nxt, char key, String type) // Run test, press key and print results
{
    // Set next colour
    Keyboard.print(key);

    curr_time = micros(); //need to run this in case board is left connected for long period as first run won't read any samples
    unsigned long start_time = micros();
    
    //50ms worth of samples @100ksps= 5000 samples
    //50ms worth of samples @129ksps = 6451 samples
    digitalWrite(3, HIGH);
    /////////////////////////////////////////////////////////////
    //                    Take ADC Readings                    //
    /////////////////////////////////////////////////////////////
    // Loop for samplingTime microseconds
    while(curr_time <= (start_time + (samplingTime - 1)))
    {
      ADC0->SWTRIG.bit.START = 1; //Start ADC 
      while(!ADC0->INTFLAG.bit.RESRDY); //wait for ADC to have a new value
      adcBuff[sample_count] = ADC0->RESULT.reg; //save new ADC value to buffer @ sample_count position  
      sample_count++; //Increment sample count
      curr_time = micros(); //update current time
    }
    digitalWrite(3,LOW);
    ADC0->SWTRIG.bit.START = 0; //Stop ADC 
  
    /////////////////////////////////////////////////////////////
    //                       Print Readings                    //
    /////////////////////////////////////////////////////////////
    // Get how long the samples took to capture in microseconds
    int timeTaken = curr_time - start_time;
    //Print from & to RGB values, time taken, sample count and all captured results
    Serial.print(type);
    Serial.print(curr);
    Serial.print(",");
    Serial.print(nxt);
    Serial.print(",");
    Serial.print(timeTaken);
    Serial.print(",");
    Serial.print(sample_count);
    Serial.print(",");
    for (int i = 0; i < sample_count; i++)
    {
        Serial.print(adcBuff[i]);
        Serial.print(",");
    }
    Serial.println();
    
    sample_count = 0; //reset sample count
    
    //As using Serial slows the adc down, we take the time after Serial was used.
    curr_time = micros();
}

void digitalPotWrite(int value)
{
  SPI.beginTransaction(settingsA);
  digitalWrite(CS,LOW);
  SPI.transfer(address);
  SPI.transfer(value);
  digitalWrite(CS,HIGH);
  SPI.endTransaction();  
}

int checkUSBVoltage(int l) // Check USB voltage is between 4.8V and 5.2V
{
  int counter = 0;
  while (counter < l)
  {
    ADC1->SWTRIG.bit.START = 1; //Start ADC1 
    while(!ADC1->INTFLAG.bit.RESRDY); //wait for ADC to have a new value
    adcBuff[counter] = ADC1->RESULT.reg;
    counter++; 
  }
  Serial.print("USB V:");
  for (int i = 0; i < counter; i++)
      {
        Serial.print(adcBuff[i]);
        Serial.print(",");
      }
  Serial.println();
  Serial.println();
  ADC1->SWTRIG.bit.START = 0; //Stop ADC 
  return 1;
}

void runGammaTest()
{
    Serial.println("G Test Starting");
    if (extendedGamma)
    {
        int arrSize = sizeof(extGammaArr) / sizeof(int);
        for (int i = 0; i < arrSize; i++)
        {
          Keyboard.print(extGammaKeys[i]);
          delay(200);
          runADC(extGammaArr[i], extGammaArr[i], extGammaKeys[i], "Gamma: ");
          delay(200);
        }
    }
    else
    {
        int arrSize = sizeof(RGBArr) / sizeof(int);
        for (int i = 0; i < arrSize; i++)
        {
          Keyboard.print(Keys[i]);
          delay(200);
          runADC(RGBArr[i], RGBArr[i], Keys[i], "Gamma: ");
          delay(200);
        }
    }
    Serial.println("G Test Complete");
}

void runInputLagTest(int timeBetween)
{
  //Keyboard.print('1');
  //Keyboard.print('Q');
  delay(50);
  int sampleTime = 200000;
  if (timeBetween == 100)
  {
    sampleTime = 100000;
  }
  curr_time = micros();
  unsigned long clickTime = micros();
  //Mouse.click(MOUSE_LEFT);
  //Mouse.click(MOUSE_LEFT);
  Keyboard.print('6');
  unsigned long start_time = micros();  
  while(curr_time <= (start_time + (sampleTime - 1)))
  {
    ADC0->SWTRIG.bit.START = 1; 
    while(!ADC0->INTFLAG.bit.RESRDY); 
    adcBuff[sample_count] = ADC0->RESULT.reg;  
    sample_count++; 
    curr_time = micros(); 
  }
  ADC0->SWTRIG.bit.START = 0; 
  int timeTaken = curr_time - start_time;
  Keyboard.print('1');
  
  Serial.print("IL:");
  Serial.print(start_time - clickTime);
  Serial.print(",");
  Serial.print(timeTaken);
  Serial.print(",");
  Serial.print(sample_count);
  Serial.print(",");
  for (int i = 0; i < sample_count; i++)
  {
    Serial.print(adcBuff[i]);
    Serial.print(",");
  }
  Serial.println();
  Keyboard.print('1');
  Keyboard.print('1');
  sample_count = 0; //reset sample count
    
  curr_time = micros();
}

void checkLatency() {
  delay(100);
  Keyboard.print('Q');
  delay(100);
  runADC(1000,1000,'F',"TL:");
  char input[INPUT_SIZE + 1];
  unsigned long startTime = micros();
  while (curr_time < (startTime + 3000))
  {
    curr_time = micros();
    for (int i = 0; i < INPUT_SIZE + 1; i++)
    {
      input[i] = ' ';
    }
    byte sized = Serial.readBytes(input, INPUT_SIZE);
    input[sized] = 0;  
    if (input[0] == 'X')
    {
      break;
    }
    else if (input[0] == 'S')
    {
      int t = input[1] - '0';
      t++;
      samplingTime = 50000 * t;
      break;
    }  
  }
}

int convertHexToDec(char c) {
  if (c <= 57) {
    return c - '0';  // Convert char to int
  } else {
    return c - 55;
  }
}

void setup() {
  pinMode (CS, OUTPUT);
  pinMode (3, OUTPUT);
  SPI.begin();
  
  digitalPotWrite(0x80);
  ADC_Clocks();
  ADC_Init(ADC0); //Initialise ADC0
  ADC_Init(ADC1); //Initialise ADC1
  Serial.begin(115200); //Open Serial connection at 115200 baud
  while(!Serial); //Wait for Serial to be connected
  Keyboard.begin(); //Open keyboard connection over USB
  pinMode(buttonPin, INPUT_PULLUP); //Button input on pin 2
  pinMode(13, OUTPUT); //Onboard LED
  Serial.println("Begin...");
}
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

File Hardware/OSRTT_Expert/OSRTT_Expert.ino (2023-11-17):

#include <SPI.h>
#include <Wire.h>
#include <Adafruit_GFX.h>
#include <Adafruit_SSD1306.h>

#define SCREEN_WIDTH 128
#define SCREEN_HEIGHT 64
#define OLED_RESET -1
#define SCREEN_ADDRESS 0x3C 
Adafruit_SSD1306 display(SCREEN_WIDTH, SCREEN_HEIGHT, &Wire, OLED_RESET);
#define LOGO_HEIGHT   64
#define LOGO_WIDTH    128
static const unsigned char PROGMEM logo_bmp[] = {
 0x00, 0x1f, 0xff, 0xff, 0xff, 0xff, 0xff, 0xff, 0xff, 0xff, 0xff, 0xff, 0xff, 0xff, 0xe0, 0x00, 
  0x00, 0x3f, 0xff, 0xff, 0xff, 0xff, 0xff, 0xff, 0xff, 0xff, 0xff, 0xff, 0xff, 0xff, 0xf0, 0x00, 
  0x00, 0x7f, 0xff, 0xff, 0xff, 0xff, 0xff, 0xff, 0xff, 0xff, 0xff, 0xff, 0xff, 0xff, 0xfc, 0x00, 
  0x00, 0xff, 0xff, 0xff, 0xff, 0xff, 0xff, 0xff, 0xff, 0xff, 0xff, 0xff, 0xff, 0xff, 0xfc, 0x00, 
  0x01, 0xff, 0xff, 0xff, 0xff, 0xff, 0xff, 0xff, 0xff, 0xff, 0xff, 0xff, 0xff, 0xff, 0xfe, 0x00, 
  0x03, 0xfe, 0x00, 0x00, 0x00, 0x00, 0x00, 0x00, 0x00, 0x00, 0x00, 0x00, 0x00, 0x01, 0xff, 0x00, 
  0x07, 0xf8, 0x00, 0x00, 0x00, 0x00, 0x00, 0x00, 0x00, 0x00, 0x00, 0x00, 0x00, 0x00, 0x7f, 0x80, 
  0x07, 0xf0, 0x00, 0x00, 0x00, 0x00, 0x00, 0x00, 0x00, 0x00, 0x00, 0x00, 0x00, 0x00, 0x3f, 0x80, 
  0x07, 0xf0, 0x00, 0x00, 0x00, 0x00, 0x00, 0x00, 0x00, 0x00, 0x00, 0x00, 0x00, 0x00, 0x1f, 0x80, 
  0x07, 0xe0, 0x00, 0x00, 0x00, 0x00, 0x00, 0x00, 0x00, 0x00, 0x00, 0x00, 0x00, 0x00, 0x1f, 0x80, 
  0x07, 0xe0, 0x00, 0x00, 0x00, 0x00, 0x00, 0x00, 0x00, 0x00, 0x00, 0x00, 0x00, 0x00, 0x1f, 0x80, 
  0x07, 0xe0, 0x3f, 0xf8, 0x00, 0x7f, 0xe0, 0x1f, 0xff, 0x0f, 0xff, 0xfd, 0xff, 0xff, 0xdf, 0x80, 
  0x07, 0xe0, 0xff, 0xfe, 0x01, 0xff, 0xf8, 0x1f, 0xff, 0x8f, 0xff, 0xff, 0xff, 0xff, 0xdf, 0x80, 
  0x07, 0xe1, 0xff, 0xff, 0x03, 0xff, 0xf8, 0x1f, 0xff, 0xcf, 0xff, 0xff, 0xff, 0xff, 0xdf, 0x80, 
  0x07, 0xe3, 0xff, 0xff, 0x03, 0xff, 0xfc, 0x1f, 0xff, 0xe7, 0xff, 0xfc, 0xff, 0xff, 0x9f, 0x80, 
  0x07, 0xe3, 0xc0, 0x0f, 0x83, 0xc0, 0x3c, 0x1e, 0x01, 0xe0, 0x1e, 0x00, 0x01, 0xe0, 0x1f, 0x80, 
  0x07, 0xe3, 0xc0, 0x07, 0x87, 0x80, 0x3c, 0x1e, 0x01, 0xe0, 0x1e, 0x00, 0x01, 0xe0, 0x1f, 0x80, 
  0x07, 0xe3, 0xc0, 0x07, 0x87, 0x80, 0x00, 0x1e, 0x01, 0xe0, 0x1e, 0x00, 0x01, 0xe0, 0x1f, 0x80, 
  0x07, 0xe3, 0xc0, 0x07, 0x83, 0xc0, 0x00, 0x1e, 0x01, 0xe0, 0x1e, 0x00, 0x01, 0xe0, 0x1f, 0x80, 
  0x07, 0xe3, 0xc0, 0x07, 0x83, 0xf0, 0x00, 0x1e, 0x01, 0xe0, 0x1e, 0x00, 0x01, 0xe0, 0x1f, 0x80, 
  0x07, 0xe3, 0xc0, 0x07, 0x83, 0xff, 0xf0, 0x1e, 0x07, 0xe0, 0x1e, 0x00, 0x01, 0xe0, 0x1f, 0x80, 
  0x07, 0xe3, 0xc0, 0x07, 0x81, 0xff, 0xf8, 0x1f, 0xff, 0xc0, 0x1e, 0x00, 0x01, 0xe0, 0x1f, 0x80, 
  0x07, 0xe3, 0xc0, 0x07, 0x80, 0xff, 0xfc, 0x1f, 0xff, 0xc0, 0x1e, 0x00, 0x01, 0xe0, 0x1f, 0x80, 
  0x07, 0xe3, 0xc0, 0x07, 0x80, 0x00, 0x7c, 0x1f, 0xff, 0x00, 0x1e, 0x00, 0x01, 0xe0, 0x1f, 0x80, 
  0x07, 0xe3, 0xc0, 0x07, 0x80, 0x00, 0x1e, 0x1e, 0x1e, 0x00, 0x1e, 0x00, 0x01, 0xe0, 0x1f, 0x80, 
  0x07, 0xe3, 0xc0, 0x07, 0x80, 0x00, 0x1e, 0x1e, 0x1f, 0x00, 0x1e, 0x00, 0x01, 0xe0, 0x1f, 0x80, 
  0x07, 0xe3, 0xc0, 0x07, 0x87, 0x00, 0x1e, 0x1e, 0x0f, 0x00, 0x1e, 0x00, 0x01, 0xe0, 0x1f, 0x80, 
  0x07, 0xe3, 0xc0, 0x07, 0x87, 0x80, 0x1e, 0x1e, 0x0f, 0x80, 0x1e, 0x00, 0x01, 0xe0, 0x1f, 0x80, 
  0x07, 0xe3, 0xe0, 0x1f, 0x07, 0xc0, 0x7c, 0x1e, 0x07, 0xc0, 0x1e, 0x00, 0x01, 0xe0, 0x1f, 0x80, 
  0x07, 0xe1, 0xff, 0xff, 0x07, 0xff, 0xfc, 0x1e, 0x03, 0xc0, 0x1e, 0x00, 0x01, 0xe0, 0x1f, 0x80, 
  0x07, 0xe1, 0xff, 0xfe, 0x03, 0xff, 0xf8, 0x1e, 0x03, 0xe0, 0x1e, 0x00, 0x01, 0xe0, 0x1f, 0x80, 
  0x07, 0xe0, 0x7f, 0xfc, 0x01, 0xff, 0xf0, 0x1e, 0x01, 0xe0, 0x1e, 0x00, 0x01, 0xe0, 0x1f, 0x80, 
  0x07, 0xe0, 0x07, 0xc0, 0x00, 0x00, 0x00, 0x00, 0x00, 0xc0, 0x00, 0x00, 0x00, 0x00, 0x1f, 0x80, 
  0x07, 0xe0, 0x00, 0x00, 0x00, 0x00, 0x00, 0x00, 0x00, 0x00, 0x00, 0x00, 0x00, 0x00, 0x1f, 0x80, 
  0x07, 0xe0, 0x00, 0x00, 0x00, 0x00, 0x00, 0x00, 0x00, 0x00, 0x00, 0x00, 0x00, 0x00, 0x1f, 0x80, 
  0x07, 0xe0, 0x00, 0x00, 0x00, 0x00, 0x00, 0x00, 0x00, 0x00, 0x00, 0x00, 0x00, 0x00, 0x1f, 0x80, 
  0x07, 0xf0, 0x00, 0x00, 0x00, 0x00, 0x00, 0x00, 0x00, 0x00, 0x00, 0x00, 0x00, 0x00, 0x1f, 0x80, 
  0x07, 0xf0, 0x00, 0x00, 0x00, 0x00, 0x00, 0x00, 0x00, 0x00, 0x00, 0x00, 0x00, 0x00, 0x3f, 0x80, 
  0x07, 0xf8, 0x00, 0x00, 0x00, 0x00, 0x00, 0x00, 0x00, 0x00, 0x00, 0x00, 0x00, 0x00, 0x7f, 0x80, 
  0x03, 0xfe, 0x00, 0x00, 0x00, 0x00, 0x00, 0x00, 0x00, 0x00, 0x00, 0x00, 0x00, 0x01, 0xff, 0x00, 
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
};

void clearDisplayBuffer() {
  display.clearDisplay();
  display.println(); // empty buffer to save OLED life.
  display.display();
}

void screensaver() {
  
}

void drawSplashScreen(void) {
  display.clearDisplay();

  display.drawBitmap(
    (display.width()  - LOGO_WIDTH ) / 2,
    (display.height() - LOGO_HEIGHT) / 2,
    logo_bmp, LOGO_WIDTH, LOGO_HEIGHT, 1);
  display.display();
  delay(1000);
}

void oledAwaitingSerial(String keyword) {
  display.clearDisplay();

  display.setTextSize(2);
  display.setTextColor(SSD1306_WHITE); 
  display.setCursor(0, 0);     
  display.println(F("AWAITING"));
  display.println(F("DESKTOP"));
  display.println(keyword);
  display.println(F("..."));
  display.display();
  delay(100);
}

void oledFourLines(String keyword1, String keyword2, String keyword3, String keyword4) {
  display.clearDisplay();

  display.setTextSize(2);
  display.setTextColor(SSD1306_WHITE); 
  display.setCursor(0, 0);     
  display.println(keyword1);
  display.println(keyword2);
  display.println(keyword3);
  display.println(keyword4);
  display.display();
  delay(100);
}

void oledTestRunning(int fromRGB, int toRGB, int runCount) {
  display.clearDisplay();

  display.setTextSize(1);
  display.setTextColor(SSD1306_WHITE); 
  display.setCursor(0, 0);     
  display.println(F("RUNNING TEST:"));
  display.setTextSize(2);
  display.print(F("Run "));
  display.println(runCount);
  display.setTextSize(1);
  display.println();
  display.setTextSize(2);
  display.print(F("RGB "));
  display.println(fromRGB);
  display.print(F("RGB "));
  display.println(toRGB);

  display.display();
  //delay(100);
}

void rotateDisplay(int rotation)
{
  // 0 = Standard
  // 1 = Right
  // 2 = Left
  display.setRotation(rotation);
}

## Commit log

2021-09-24 Changed button cutout position & dropped height of back piece to account for resin printing + moved USB port hole down too.
    [V3Back.stl, V3Base.stl]
2021-09-24 Added board firmware (Arduino)
2021-10-03 So. Many. Changes. Added logo/icon, updated README, added FPS Limit setting, fixed averaging, improved averaging data to now use moving average, analyse results is now a toggle, tested autoupdater fu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
    [OSRTT_Full_Code.ino]
2021-10-05 Fixed a lot, added (untested) get focused window, OVERSHOOT CALCULATIONS ARE BROKEN. Removed ed pelt changepoint detector as it not useful here
    [OSRTT_Full_Code.ino]
2021-10-07 SO. MUCH. STUFF. New brightness calibration window, more error checking, more reliable device comms, icon added, case now has space for new shorter button caps to actuate. I'd say this is 90-95% read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
    [V3Base.stl, V3Top.stl]
2021-10-09 Loads more changes, Fixed a few bugs and adds saved settings for runs and refresh rate. May add more settings options like results settings (10-90%, overshoot light vs RGB etc). Added results templat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
    [Results Template.xlsx]
2021-10-18 Updated UE4 project, fixed testing scenario bug, security issues with installer and NSI script (will need to publish both an installer and 'update files' zip on releases now though. ADDED USER SETTIN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
    Also fixed so many bugs, added window focuesed hook which pauses the test if game isn't selected and quits the game is the board disconnects.
    [Results Template.xlsx]
2021-11-14 Lots of bugfixes - USB voltage stability check, brightness stability check, USB voltage offset, improved low end (0-26-0) processing - could do with further denoising but not sure if possible without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
    Also added new output options including smoothed raw data.
    [OSRTT_Full_Code.ino]
2021-11-17 Final set of changes before publishing V1.0... maybe. New PCB design, new USB voltage and brightness stability checks, new settings and updates to results template.
    [Results Template.xlsx]
2021-11-21 Fixed hardware timer issue, added minimise to tray/taskbar option, added launch check for program open already, fixed overshoot settings mixup.
    [OSRTT_Full_Code.ino]
2021-11-24 Updated case (still not finished), updated PCB, bug fixes and tweaks.
    [V3Back.stl, V3Base.stl, V3Top.stl]
2021-11-25 Created graph view template, improved clipped curve measurements, began fixing overshoot, fixed firmware update issues
    [Graph View Template.xlsm]
2021-11-26 Updated graph view template and tweaked averaging start/end values to get more accurate readings especially for overshoot
    [Graph View Template.xlsm]
2021-12-06 New gamma test, reduced test count to 6x6, lots of bug fixes, system uptime check, new debug settings, revised case design, new gamma processing (cubic interpolation), new FPS setting options
    [Graph View Template.xlsm, Old Results Template.xlsx, Results Template.xlsx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]
2021-12-10 moved app running call to after 1s delay in board connection sequence
2021-12-24 UNFINISHED test changes,cubic interpolation, visual response rating and lots more
    [Results Template.xlsx]
2021-12-25 I think that has fixed a lot. New test works (I think). Processing and averaging has been fixed. Trimmed measurements have been updated to have better detection triggers. Added extra check for if an 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
    [Results Template.xlsx]
2022-01-05 LOTS! Input lag testing and UI redesign, processing code tweaks, bug fixes, tweaks to excel files, case tweaks, new PCB design, & plenty more I can't remember
    [Graph View Template.xlsm, Results Template.xlsx, V3Back.stl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]
2022-01-11 A number of updates... Initial push of docs
    [Graph View Template.xlsm, V3Base.stl, V3Top.stl]
2022-01-14 updates to input lag and response time testing, changing some default settings and minor bug fixes and tweaks to make it (HOPEFULLY) stable and ready for an initial launch.
    [OSRTT_Full_Code.ino]
2022-01-14 Updates to templates, added circuit diagram, uploaded arduino libraries required just in case.
    [Graph View Template.xlsm, Old Results Template.xlsx, Results Template.xlsx]
2022-01-19 Added VSync to UE4, setting in ino and C#, reverted graph view template to much faster version, fixed a number of bugs, added device reset on connection in case of crashed/failed previous tests, move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
    [Graph View Template.xlsm]
2022-01-19 minor bug fixes to not invoking methods correctly
    [OSRTT_Full_Code.ino]
2022-01-30 fixed complete response time bug (mostly)
    [Results Template.xlsx]
2022-02-04 Fixed complete time bugs, refresh monitor list on test start, added (and hid) convert raw to graph view, added extended gamma test and rough latency on test. Fixed UE bug with initial click required 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
    [OSRTT_Full_Code.ino]
2022-02-09 New extended gamma test, fixed long 10% non gamma corrected perceived response time results, added pre-test latency check, improved vsync and framerate control, improved UE4 performance & vsync contr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
    [OSRTT_Full_Code.ino]
2022-03-19 Huge WIP updates to the results view. Graphs now work (small processing options bugs), multi-run imports, and heatmaps are closeTM.
    [Graph View Template.xlsm]
2022-04-26 Heatmaps & Graphs - complete (I hope). So so many changes, more than I can remember.
2022-05-12 Added serial number check, smoothed data view, updated readme and minor bug fixes and tweaks.
    [OSRTT_Full_Code.ino]
2022-05-12 Update readme and add button
2022-05-24 Added live view mode, fixed minor bugs like USB Voltage readout
    [OSRTT_Full_Code.ino]
2022-05-24 Updated path for save png button on live view
2022-05-26 Fixed test running failure, improved reliability, updated versions
    [OSRTT_Full_Code.ino]
2022-05-27 Adding to settings (unfinished) and minor bug fixes to heatmaps
2022-06-03 Updated firmware code to install libraries just in case
2022-06-03 Added heatmaps key settings page
2022-06-28 Added overdrive mode stage, fixed processing time delay
2022-07-01 update cad model and add buy a kit button
    [V4Base.stl, V4Lid.stl]
2022-07-27 Major update to visual response rating, fix for pro firmware, remove test button..
    [file2.ino]
2022-08-08 Fixed overshoot bug and gamma curve bug
    [file2.ino]
2022-10-14 Replaced Input Lag mode with DirectX Code. Added input lag results view. Added new tab to XLSX file. Fix monitor name failure. Moved input lag processing to processdata.
    [Results Template.xlsx]
2022-10-19 Version bump, minor fixes for directX mode andresultsview
    [file3.ino]
2022-11-06 Lot of minor changes. Adding support for more input lag clicks, fixes to results view and new firmware flasher tool
    [OSRTT_Full_Code.ino, file3.ino]
2022-11-11 Fixed show date and extra info, increased input lag now snaps to steps of 10, fixed save as png on input lag results view, fixed broken date setting
    [OSRTT_Full_Code.ino, file2.ino, file3.ino]
2022-11-24 fixed click count and processing error for input lag testing
    [OSRTT_Full_Code.ino, file2.ino, file3.ino]
2023-01-25 added autosaving PNG setting, repeated board type decleration
2023-01-25 added cancel button to cancel test if started accidentally
2023-02-09 Added a number of new minor features/bug fixes including saving user settings separately to not overwrite on update
    [file2.ino, file3.ino]
2023-05-02 improved firmware to work with newer Pro boards
2023-05-04 Fixed firmware update bug for Pro boards
2023-05-11 Fixed OSRTT V1 not running input lag test, bumped version to auto install from pre-compiled binary
    [OSRTT_Full_Code.ino]
2023-06-23 updated OSRTT firmware to fix detection issues
    [OSRTT_Full_Code.ino]
2023-12-10 Fixed FPS Limit function in firmware
    [OSRTT_Full_Code.ino, file2.ino, file3.ino]
2024-02-14 Added pot value timeout, disabled brightness cal for pro, fixed N/A folder bug, make 100ms default capture time
    [file2.ino, file3.ino]
2024-08-10 Added flicker filtering, and support for expert
2024-08-16 Fixed flicker filter settings and out of bounds error
2026-09-22 (A lot, some WIP) Refactoring functions to separate files to make maintenence easier. New filtering and smoothing functions. Starting to migrate to materialskin for the UI. Make sure program doesn't 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
